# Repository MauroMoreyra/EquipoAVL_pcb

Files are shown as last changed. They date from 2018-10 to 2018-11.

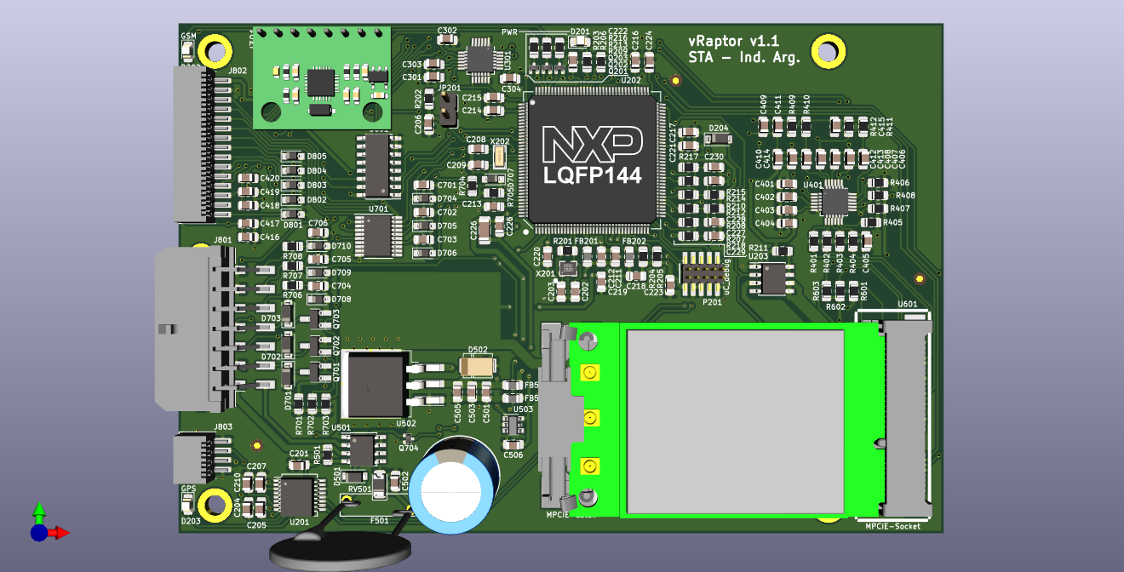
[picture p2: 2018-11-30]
TrackerAVL/images and 3d models/EquipoAVL_vRaptor_v1.1.png

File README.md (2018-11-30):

# EquipoAVL_pcb - vRaptor

## Guía rápida para manejo de versiones

- Habilitar modulo GitFlow en GitKraken.
- Creación de nueva versión: estando posicionado en rama "develop" o "master", GitFlow > Start Release > Nombre "vX.X" (número de versión).
- Finalización de nueva versión: GitFlow > Finish release, tildando "Delete branch". De esta forma se vuelcan a las ramas "develop" y "master" los cambios de la versión del release. A su vez se genera un TAG con el nombre del release "vX.X", que quedará de referencia histórica para futura consulta.

## Mejoras pendientes (previa validación)

- PCB 4 capas.
- Componentes en ambas caras.
- Revisar tamaño huellas, encapsulados.
- Modificar huellas para que posean el área que las delimita, así se valida el ERC en forma integral (con todos los checks activados).
- Ver otros errores del ERC integral.
- Verificar diseño 1.1 y corregir errores en caso de que existan.
- Verificar margenes tolerados por fabricantes, con el fin de achicar tamaños pistas y separación entre las mismas.
- Agregar información a componentes (desde esquemático).
- Poner conector DB15 en PCB, para utilizar así un cable VGA-DB15 directamente hacia la consola. Revisar tema gabinete.
- Capacitor C504 modificar para que sea de menor tamaño, reducir capacidad? low profile? investigar. Es muy alto (25mm).
- Revisar margenes laterales por tema gabinete - guia para su inserción. Revisar componentes situados muy sobre los bordes.
- Footprints IPC compatible: Revisar normativa IPC 7351 referente a los footprints recomendados de los componentes, ya que no es aconsejable utilizar los footprints recomendados por los fabricantes de las partes (se puede observar que para un mismo encapsulado, distintos fabricantes recomiendan footprints distintos, aunque varíen muy levemente). Revisar generador de footprints que sigue normativa IPC: https://www.pcblibraries.com/ a través del Library Expert.
- Footprints IPC compatible: Revisar densidad de componentes. Esto define el keepout del footprint, o sea, la distancia minima de separación con otro componente. Se recomienda usar una densidad "Normal" según el Library Expert.
- Revisar Bottom Paste de componentes de potencia (ej: LD1085), ya que IPC recomienda una "huella" de pasta de estaño con características especiales (tipo grilla, vías o microvías de disipación en cierta ubicación, etc.).

## Historial de versiones

**Versión 1.1**
- [Referencias de diseño](https://github.com/MauroMoreyra/EquipoAVL_pcb/blob/release/vRaptor-v1.1/Referencias%20de%20dise%C3%B1o%20v1.1.md).
- Se corrige el acceso de las pistas a los pads de los componentes, ahora lo hacen a 90° (no en diagonal). También, en caso de que a un pad entre y salga una pista, ahora ambas lo hacen con el mismo grosor (regla de diseño: ancho pista menor ancho pad, ya que facilita así el soldado de los componentes al no haber tanta transferencia térmica sobre las pistas).
- Se redimensiona el ancho de pistas, muchas se angostaron.
- Se modifican huellas de componentes QFN (```MPU-6050``` y ```NAU8814```), ahora tienen pads más largos (1.5mm) para facilitar el soldado manual (ese es el ancho de la    superficie del pad que la punta del soldador debe hacer contacto -punta ```900m-t-2c``` preferentemente).
- Se agrega tira de pines sobre conexiones de ```MPU-6050``` para tener como alternativa la posiblidad de colocar placa arduino de ese componente (inserción más fácil).

**Versión 1.0**
- Primera versión, entregable de materia Diseño de PCB.

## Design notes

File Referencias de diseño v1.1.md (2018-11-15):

## Referencias de diseño

- Mayer (Tecnología 8 mils)
- Pistas: 1.5; 1; 0.75; 0.5; 0.25; 0.20 [mm]
- Vías: 0.8 - Agujero: 0.4 [mm]
- Márgen: 0.25 mm
- Pista más delgada: 0.2 mm
- Dist. a borde: 0.3 mm

## STACK-UP

- FR4 1.6 mm Dual layer
- Componentes en capa superior
- Máscara anti-soldante: Azul
- Sin requerimientos especiales
- Terminación: HASL c/Pb
- Espesor de Cu: 1oz

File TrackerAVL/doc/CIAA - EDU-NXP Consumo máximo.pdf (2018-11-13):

Hola Juan,

Ya tengo armado el cálculo de potencia o de consumo para la EDU-CIAA.

Lo puntos más importantes serian:

- Según la hoja de datos del LPC4337 potencia máxima de disipación de del micro que es de 1,5W, lo que da una corriente máxima de 450mA.
- Como dato extra esta tiene un calculo de consumo del micor con un while(1) y sin periféricos habilitados:

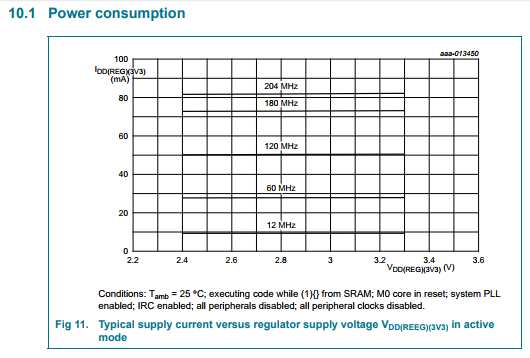
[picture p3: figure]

- A todo esto hay que sumarle el consumo del chip FTDI2232 que es de 30mA.

Así que estiramos alrededor de 500mA de consumo.

Otro dato extra: hay un link (seguramente lo conoces), que está bastante piola para sacar el ancho de la pista en forma sencilla:

hp://circuitcalculator.com/wordpress/2006/01/31/pcb-trace-width-calculator/

Por ultimo en el impreso de la EDU-CIAA la pista es de 30mils (aprox 1,5A), mas que suficiente para la aplicación.

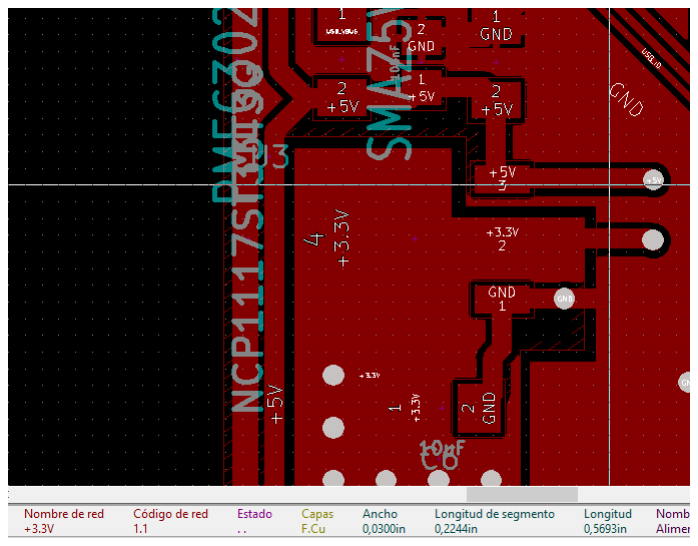
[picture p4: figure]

Avisame en que otra cosa te puedo ayudar,

Saludos,

Jorge.

### Re: Miercoles 30 de 19 a 22 en CADIEEL

1 de 1 | 13/09/2017 04:49 p.m.

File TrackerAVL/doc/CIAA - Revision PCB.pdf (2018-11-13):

# Revisión de PCB

Autor | Koenig Mauro
Versión | 0.1
Ultima revisión | 30-04-2014

Revisión PCB de la CIAA | Emtech S.A.

Página 2 de 8

### Contenido

Revisión de esquemático de la CIAA | Emtech S.A.

Página 3 de 8

### Revisiones

Fecha | Versión | Modificaciones
Febrero 3, 2014 0.1 | | Versión original

Página 4 de 8

## Introducción

El siguiente documento detallan comentarios sobre el diseño PCB de la CIAA-NXP y las tareas realizadas sobre el mismo.

Página 5 de 8

## Revisión

Lista de modificaciones a realizar al diseño: _Agregar los holes de 4mm OK
_Agregar 2 pines +24VDC a P12 OK
_Cambio de Part Number de TH9 a MF-MSMF110. OK _Cambiar ubicación de leds dentro de ventana. OK _Alineación de MOSFET. OK
_Cambiar C16 a EMVA350ARA471MKE0S OK
_Cambiar P8 a CONN HDR 1.27MM SMD AU 10POS
(http://www.digikey.com/product-detail/es/M50-3600542/952-1389-ND/2264370) OK _Agregar fiduciales OK
_Rehacer conectores USB, colocar MICRO USB.OK
_Cambiar el DB9 por PN:K22X-E9P-NJ, http://www.mouser.com/ds/2/222/K22X-220929.pdf OK _BT1, hay que intercambiar pin 2 con 3 OK
_Ver PAD GND de U1. OK

SEGUNDA REVISIÓN:

1. ¿Es posible aumentar el tamaño de los pads de T1...T12 (NSI45020)? Esto es para mejorar su disipación térmica, porque estamos un poco jugados en este sentido. Aunque sea dibujarles un rectángulo de cobre encima a cada pad, o directamente agrandar un poco los pads en la librería, creo que así es más rápido. Insisto en que necesitamos sí o sí mejorar la disipación térmica de estos reguladores.
OK se pasaron de 0.007 x 0.0035 a 0.009 x 0.005
2. ¿Se pueden agregar dos agujeros más de 4mm como los de las esquinas, pero para sujetar las expansiones que se conecten al PCB de la CIAA? Vemos que hay lugar abajo a la izquierda (a la derecha de los conectores USB) y abajo a la derecha (a la izquierda del conector DB9).
Agregados dos agujeros de 4 mm y uno de 2.5mm entre los conectores de expansión.
3. ¿Se puede girar un poco más el conector BT1 en sentido de las agujas del reloj? Creemos que al colocar la batería, ésta podría tocar contra el primer pin de la bornera J19.
Se giró 10º más, creo que si lo giramos más, puede tocar la chapa del soporte en el pin de J19

### 4. _Micro USB: Según esto, el borde del PCB debe estar a 1.45mm del

centro de los pads, y en el PCB de la CIAA yo medí 2.3mm. Corregido.

### 5. _Disipación térmica de los NSI45020 (T1...T12). Tendríamos que tratar

al menos de acercarnos a los 100mm^2 de área por pad, es decir cada pad debería ser de 1cm x 1cm. Sé que esto es casi imposible, pero si al menos dibujas un polígono de 10mm x 10mm asociado a la net de

Página 6 de 8

cada pad, que el KiCad lo rellene como pueda sin tocar otros nets, así nos acercamos lo más que podamos a ese área. ¿Me explico? Tenemos que tratar de sumar superficie de cobre de la forma que podamos.
Con respecto a T1 a T8 va mi consulta: En serie con estos diodos esta lo siguiente:
Diodo LL4148 200mA
Led LED ALG 0603 SMD de 72mW
Diodo de PS2801 70mW
y una R0603 100ohms 100mW que limita la corriente de entrada.

En verdad creen que hace falta modificar los pads? Perdón si estoy omitiendo alguna función más de estos reguladores, mi consulta surge porque la zona donde están ubicados realmente está muy poblada y los cambios van a ser notables si se necesitan estos PADs grandes. Rta:
Las cuentas de disipación están basadas en unos cálculos simples: Si el rango de tensión va de 5V a 24 (o 30V) de entrada, y queremos que por el foto diodo siempre circulen en el orden de los 10mA alguien tiene que hacer de elemento variable...eso lo hace la fuente de corriente NSI. El costo para tener este rango amplio es que no está calculado para una tensión de entrada fija, y con una R en serie lo solucionamos. Si así lo hiciéramos igual la R debería disipar... Ahora, en el peor caso tenemos 30V de entrada, quitando la caída en el 4148, el LED, etc. quedarán unos 25V regulados a 10mA de entrada => 250mW para disipar en el NSI. Con 100mm^2 en 1Oz. de cobre tiene una Rtja de 600°C/W (datasheet) da 150 grados de sobre elevación...si esto lo duplicamos por ponerlo esa superficie en cada pad la cosa baja a la mitad, 75 grados.
Una alternativa rápida que se me ocurre sería poner el NSI conectado a la Net "COM", cambiando el orden de los componentes en serie. En este caso dado que "COM" está ruteado en la capa del plano de tierra, se podría hacer allí el plano común a todos los NSI relativamente fácil, y colocando varias vías térmicas en el cátodo de cada NSI logramos buena conductividad...

MEJORADO

6. Todas las trazas a borneras en general deben ser de 20mils (Relays, MOSFET, +24), en líneas generales desde J10 a J15 todas las salidas digitales
AGREGADO

### 7. Anchos de traza hacia las borneras, como dice Juan, deberían ser de 0.5 o 0.75mm como mínimo. Por ejemplo la N-00000437, que saca

24V a través del polyswitch de 1A. Habría que chequear todas las pistas que llegan a los bornes.
AGREGADO

### 8. Los transceivers RS485 compatibles con Profibus que encontramos

son todos de 5V. Después de conversarlo con Juan, para simplificarte (al menos un poco) el trabajo, pensamos que es mejor no poner el

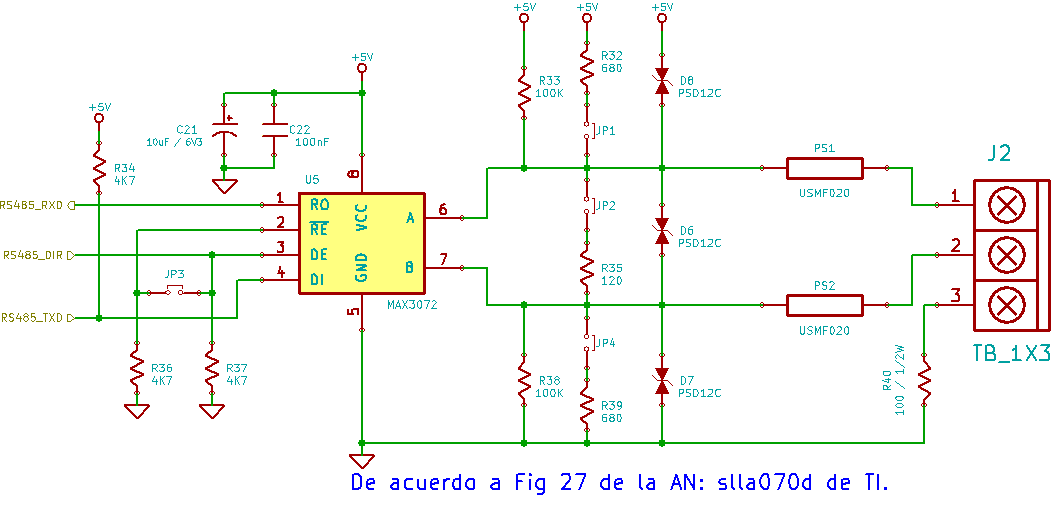
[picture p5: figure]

Página 7 de 8

puente soldable y cambiar todo el circuito RS485 a 5V. Te pego acá una imagen de cómo quedaría el esquemático (básicamente cambié los puntos +3.3V a +5V). Juan me avisó que los resistores del bus también cambian, pero eso no afecta el ruteo, así que por ahora dejamos esos valores.

CAMBIADO

### 9. Orden de los LEDs IN: 0 1 2 3 4 5 7 6 y LEDs DOUT: 5 4 7 6. Aunque

está perfecta la aclaración en el silkscreen, yo trataría de ordenar los LEDs para que queden en orden.
CORREGIDO

### 10. Los cuatro agujeros están "casi bien", pero creo que se puede mejorar

un poco su ubicación. O sea, la distancia entre H3 y H2 creo que es alrededor de un 1 mm mayor a lo que debería ser, y la distancia entre H3 y H1 es alrededor de 2 mm mayor a la que debería ser. CORREGIDO
11. Además se aprecia que queda algo de espacio para agrandar el PCB, que creo que como máximo podría andar en alrededor de 138 x 86 mm.

### 12. En el esquemático del proyecto que envió Mauro, la numeración de los

pines del relé no es la misma que en el esquemático.
VERIFICADO

### 13. Tema la Pila CR2032, la verdad que no me convence mucho la

ubicación, van un par de sugerencias:
a) Cambiar de CR2032 a CR2016, va link a hojas de datos para que vean la diferencia de formato y las especificaciones. http://data.energizer.com/PDFs/cr2032.pdfhttp://data.energizer.com/PDFs/cr2016.pdf
b) Cambiar la ubicación, ponerla debajo de los USB, es decir diagonalmente opuesta, y usar porta batería SMD. Estuve viendo y no parece muy difícil, pero Mauro nos lo puede decir mejor.

### 14. Me parece que todas las tiras de pines están muy juntas, que se va

complicar al momento de armado, P12, P15 Y P9, y además P14 contra los relés.
REVISADO, SIN MODIFICACION

### 15. Planos de masa, GND y GNDA están unidos tan solo en un punto en

Inner1_cu, cerca del micro. Yo suelo tomar como referencia la nota de

Página 8 de 8

aplicación adjunta, que en el caso nuestro sugiere la conexión en más de un punto.
16. Cambiar en esquemático pin out de Q2, Q4, Q8 y Q2, cambiar a G=1, D=2 y S=3. Unir con una traza de 20mils el pad TAB y pin 2. CORREGIDO

### 17. Cambiar el footprint de C1 C5 C18 C31 C34 C60 C68 C78 C21 C28 a

CAP TANT 10UF 6.3V 10% 1206 PN:T491A106K006AT7280 CORREGIDO

### 18. Cambio de C67 a 0603

CORREGIDO

### 19. Cambiar encapsulado de FTDI U17 a paso .5mm

CORREGIDO
20. Modificar vias a 25mils de diámetro y un hole de 10 mils. MODIFICADO.

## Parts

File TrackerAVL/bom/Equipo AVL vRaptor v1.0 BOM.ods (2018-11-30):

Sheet: BOM
Componente | Fabricante | Cant. | Referencia | Descripción | Código Digi-Key | Link | Comentario
ACELERÓMETROS
MPU-6050 (IC) | TDK InvenSense | 1 |  | IMU ACCEL/GYRO 3-AXIS I2C 24QFN | 1428-1007-1-ND | https://www.digikey.com/product-detail/en/tdk-invensense/MPU-6050/1428-1007-1-ND/4038010 | -
MPU-9150 (IC) | TDK InvenSense | 1 |  | IMU ACCEL/GYRO/MAG I2C 24LGA | 1428-1009-1-ND | https://www.digikey.com/product-detail/en/tdk-invensense/MPU-9150/1428-1009-1-ND/4038014 | -
MPU-9250 (IC) | TDK InvenSense | 1 |  | IMU ACCEL/GYRO/MAG I2C/SPI 24QFN | 1428-1019-1-ND | https://www.digikey.com/product-detail/en/tdk-invensense/MPU-9250/1428-1019-1-ND/4626450 | -
MÓDULO GSM/GPS
UC20-G Mini PCIe | Quectel | 1 |  | UMTS/HSPA+/GNSS Module | N/A
Conector mini PCIe PCB Hembra | Molex | 1 | PN 0679100002 | CONN PCI EXP MINI FEMALE 52POS | WM3470CT-ND | https://www.digikey.com/product-detail/en/molex-llc/0679100002/WM3470CT-ND/2405686 | -
IBUTTON
iButton DS1990A-F5+ | Maxim Integrated | 1 |  | IBUTTON SERIAL NUMBER F5 | DS1990A-F5+-ND | https://www.digikey.com/product-detail/es/maxim-integrated/DS1990A-F5/DS1990A-F5-ND/1769200 | -
Lector iButton DS9092T# | Maxim Integrated | 1 |  | IBTN PROBE W/TACTILE FEEDBACK | DS9092T#-ND | https://www.digikey.com/product-detail/es/maxim-integrated/DS9092T/DS9092T-ND/1768860 | -
Soporte iButton DS9093A+-ND | Maxim Integrated | 1 |  | IBUTTON KEY RING MOUNT BLACK | DS9093A+-ND | https://www.digikey.com/product-detail/es/maxim-integrated/DS9093A/DS9093A-ND/1769386 | -
Rf433 transceiver C1101
CONECTORES EQUIPO AVL
Connector Molex Micro-Fit 3.0 14 pos PCB Header | Molex | 1 | 430451406 | MICROFIT 3.0 RA SMT/CLIP DR TIN | WM10725TR-ND | https://www.digikey.com/product-detail/es/molex-llc/0430451406/WM10725TR-ND/3310229 | IO (10); POWER (4) | https://www.molex.com/molex/products/datasheet.jsp?part=active/0430451406_PCB_HEADERS.xml
Connector Molex Micro-Fit 3.0 14 pos Crimp Housing | Molex | 1 | 430251400 | CONN RECEPT 14POS 3MM DUAL ROW | WM2489-ND | https://www.digikey.com/product-detail/es/molex-llc/0430251400/WM2489-ND/531405 | IO (10); POWER (4) | https://www.molex.com/molex/products/datasheet.jsp?part=active/0430251400_CRIMP_HOUSINGS.xml
Micro-Fit 3.0 Crimp Terminal 20-24 AWG | Molex | 14 | 43030-0001 | CONN TERM FEMALE 20-24AWG TIN | WM1837CT-ND | https://www.digikey.com/product-detail/es/molex-llc/43030-0001/WM1837CT-ND/467810 | IO (10); POWER (4) | https://www.molex.com/molex/products/datasheet.jsp?part=active/0430300001_CRIMP_TERMINALS.xml
Connector Molex Pico-SPOX 4 pos PCB Header | Molex | 1 | 874380443 | CONN HEADER 4POS 1.5MM R/A SMD | WM7648TR-ND | https://www.digikey.com/product-detail/es/molex-llc/0874380443/WM7648TR-ND/699148 | PROG, SERIAL (4) | https://www.molex.com/molex/products/datasheet.jsp?part=active/0874380443_PCB_HEADERS.xml
Connector Molex Pico-SPOX 4 pos Crimp Housing | Molex | 1 | 874390400 | CONN HOUSING 4POS 1.5MM W/RAMP | WM2088-ND | https://www.digikey.com/products/es?keywords=87439-0400 | PROG, SERIAL (4) | https://www.molex.com/molex/products/datasheet.jsp?part=active/0874390400_CRIMP_HOUSINGS.xml
Pico-SPOX Crimp Terminal 24-26 AWG | Molex | 4 | 874210000 | CONN TERM FEMALE 24-30AWG TIN | WM9234TR-ND | https://www.digikey.com/product-detail/es/molex-llc/0874210000/WM9234TR-ND/2037270 | PROG, SERIAL (4) | https://www.molex.com/molex/products/datasheet.jsp?part=active/0874210000_CRIMP_TERMINALS.xml
Connector Molex Pico-SPOX 15 pos PCB Header | Molex | 1 | 87438-1543 | CONN HEADER 15POS 1.5MM R/A SMD | WM7659TR-ND | https://www.digikey.com/products/es?keywords=87438-1543 | INTERFAZ USR (15) | https://www.molex.com/molex/products/datasheet.jsp?part=active/0874381543_PCB_HEADERS.xml
Connector Molex Pico-SPOX 15 pos Crimp Housing | Molex | 1 | 87439-1500 | CONN HOUSING 15POS 1.5MM W/RAMP | WM2099-ND | https://www.digikey.com/product-detail/es/molex-connector-corporation/87439-1500/WM2099-ND/561778 | INTERFAZ USR (15) | https://www.molex.com/molex/products/datasheet.jsp?part=active/0874391500_CRIMP_HOUSINGS.xml
Pico-SPOX Crimp Terminal 24-26 AWG | Molex | 15 | 874210000 | CONN TERM FEMALE 24-30AWG TIN | WM9234TR-ND | https://www.digikey.com/product-detail/es/molex-llc/0874210000/WM9234TR-ND/2037270 | INTERFAZ USR (15)
CONECTORES CONSOLA
Connector D-Sub 15 pos, 3 rows, male pins |  | 1 |  | CONN D-SUB HD PLUG 15POS STR | 609-4042-ND | https://www.digikey.com/product-detail/en/amphenol-fci/10090769-P154ALF/609-4042-ND/2350290 | -
Connector D-Sub 15 pos, 3 rows, female sockets, for PCB |  | 1 |  | CONN DSUB HD RCPT 15POS R/A SLDR | 609-2802-ND | https://www.digikey.com/product-detail/en/amphenol-fci/ICD15S13E6GV00LF/609-2802-ND/1090326 | -
Connector D-Sub 15 pos, 2 rows, male pins |  | 1 |  | CONN D-SUB PLUG 15P STR SLDR CUP | G17S1510110EU-ND | https://www.digikey.com/product-detail/en/amphenol-commercial-products/G17S1510110EU/G17S1510110EU-ND/1242623 | -
Connector D-Sub 15 pos, 2 rows, female sockets, for PCB |  | 1 |  | CONN D-SUB RCPT 15POS R/A SOLDER | 609-1498-ND | https://www.digikey.com/product-detail/en/amphenol-fci/D15S33E4GV00LF/609-1498-ND/1001812 | -
Considerar usar un cable tipo VGA (ya hecho), y en el extremo opuesto “cortarlo” y colocar conector a equipo AVL. Consultar a OJOS del CIELO por largo estimado de cable. Revisar si en CHINA ya lo pueden enviar armado
AUDIO
Parlante
Micrófono
VARIOS
CI Optoacoplador para señales / cables hacia interfaz conductor |  | 1
En PCB Ojos del Cielo UNEX
FSA2567 |  |  |  | DUAL SIM SWITCH
AT45DB041D-SU | Adesto Technologies |  |  | Memoria flash tipo NOR |  | https://ar.mouser.com/ProductDetail/Adesto-Technologies/AT45DB041D-SU?qs=S%2FDyAMLKE9jN%2FzBcXSlSQg%3D%3D | -
CD4099 |  |  |  | 8-Bit Addressable Latch |  | http://www.sycelectronica.com.ar/semiconductores/CD4099.pdf | -
CD4512 |  |  |  | CMOS 8-Channel Data Selector |  | http://www.sycelectronica.com.ar/semiconductores/CD4512.pdf | -
MC908AP32 |  |  |  | uC
SN74LV4052A |  |  |  | Dual 4-Channel Analog Multiplexers and Demultiplexers

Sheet: Análisis_codec_audio_NAU8814
BOM NAU | https://www.digikey.com/products/es/capacitors/ceramic-capacitors/60?k=capacitor+4.7uF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 | - | Item | Cantidad
R1 | 1K2 |  | R = 1K2 | 2
R2 | 1K2 |  | C = 1uF | 4
C1 | 4.7uF | LOW ESR | C = 4.7uF | 6
C2 | 4.7uF | LOW ESR
C3 | 4.7uF | LOW ESR
C4 | 4.7uF | LOW ESR
C5 | 1uF | LOW ESR
C6 | 4.7uF | LOW ESR
C7 | 1uF | LOW ESR
C8 | 1uF | LOW ESR
C9 | 4.7uF | LOW ESR
C10 | 1uF | LOW ESR

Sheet: Análisis_conectores_de_borde
 |  | POSICIONES | DESCRIPCION | TIPO DE PROTECCIÓN
CONECTOR MOLEX MICRO-FIT 3.0 | 10 para IO An/Dig: | 10
Ver catalogo DIGIKEY: | > 1 dig. Para sensado de contacto (ignición) |  |  | Divisor resistivo + Zener |  | Verificar
https://www.digikey.com/products/es/connectors-interconnects/rectangular-connectors-headers-male-pins/314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 | > 6 entradas An y Dig
Catálogo WEB MOLEX | > 3 salidas Dig |  |  | Tipo Open collector? O Open Drain? |  | Verificar
https://www.molex.com/molex/products/listview.jsp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 | 4 para POWER | 4
https://www.molex.com/molex/product-search/products.action | > 1 VBAT
MOLEX Wire-to-Board Connectors | > 3 GND |  |  | PolyFuse
https://www.molex.com/molex/products/group?key=wire_to_board_connectors&channel=products | 4 para PROG / SERIAL | 4
MOLEX Micro Connector Products | > 2 GND
https://www.molex.com/molex/products/group?key=micro_connectors&channel=products | > TX |  |  | BUFFER | 1
 | > RX |  |  | BUFFER | 1
 | 15 para interfaz con conductor: | 15
 | > 4 teclado |  |  | BUFFER | 4
 | > 4 display |  |  | BUFFER | 4
 | > 2 spkr ±
 | > 2 mic ±
 | > 1 ibutton (opc.)
 | > 1 VCC |  |  | PolyFuse
 | > 1 GND
 | Posibles usos de IO An/Dig | 20 pos thru-hole > | https://www.digikey.com/product-detail/es/molex-llc/0430452000/WM4726-ND/531426
 | DEFINIR, para ver de qué cantidad es necesaria para reducir la cantidad | 24 pos thru-hole > | https://www.digikey.com/product-detail/es/molex-llc/0430452400/WM4728-ND/531428
 |  | 20 pos smd > | https://www.digikey.com/product-detail/es/molex-llc/0430452009/WM7075TR-ND/3044337
 | CONCLUSIONES:
 | > Usar conector thru-hole (para mayor resistencia al conexionado vs smd).
 | > Usar 3 conectores, divididos por funcionalidad: 1 para IO y POWER; 1 para PROG.; 1 para Interfaz conductor

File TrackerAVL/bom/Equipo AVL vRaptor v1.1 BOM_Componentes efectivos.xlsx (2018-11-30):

Id | Identificador | Empaquetado | Cantidad | Identificación | S/N | Cantidad real | Componentes Not Mounted | Comentario / Justificación
1 | J301 | PinHeader_1x08_P2.54mm_Vertical | 1 | Conn_01x08 | NO | 0
2 | H102,H101,H103,H104 | MountingHole_3.2mm_M3_Pad_Thin | 4 | MountingHole | NO | 0
3 | C401,C207,C201,C204,C205,C206,C210,C211,C212,C213,C214,C215,C216,C217,C218,C219,C220,C221,C222,C223,C224,C225,C227,C228,C229,C230,C301,C302,C303,C403,C406,C409,C410,C501,C502,C701,C702,C703,C704,C705,C706 | C_0805_2012Metric_Pad1.15x1.40mm_HandSolder | 41 | 100nF | SI | 38 | C206, C211, C212
4 | C304 | C_0805_2012Metric_Pad1.15x1.40mm_HandSolder | 1 | 2.2nF | SI | 1
5 | U401 | NAU8814_QFN-24_4x4mm_Pitch0.5mm_EPAD_HandSoldering | 1 | NAU8814 | SI | 1
6 | U301 | InvenSense_QFN-24_4x4mm_P0.5mm_HandSoldering | 1 | MPU-6050 | SI | 1
7 | U601 | mpcie-socket-latch | 1 | MPCIE-Socket | SI | 1
8 | U202 | LQFP144-M05 | 1 | LPC4337JBD144 | SI | 1
9 | U801 | SOIC-16_3.9x9.9mm_P1.27mm | 1 | 74HC4053 | SI | 1
10 | X201 | FA238V-XTAL | 1 | 12MHz | SI | 1
11 | U501,U203 | SOIC-8_3.9x4.9mm_P1.27mm | 2 | STS8C5H30L | SI | 1 | U203
12 | R501,R204,R205,R207,R210,R211,R214,R217,R405,R406,R407,R408,R601,R602,R603,R701,R702,R703 | R_0805_2012Metric_Pad1.15x1.40mm_HandSolder | 18 | 10K | SI | 17 | R211 | R211: por optarse secuencia de reset mediante #PERST
13 | FB502,FB501 | L_0805_2012Metric_Pad1.15x1.40mm_HandSolder | 2 | HZ0805E601R-10 | SI | 2
14 | C202,C203,C208,C209,C405 | C_0805_2012Metric_Pad1.15x1.40mm_HandSolder | 5 | 20pF | SI | 5
15 | C226 | C_1206_3216Metric_Pad1.42x1.75mm_HandSolder | 1 | 10uF 10V | SI | 1
16 | C402,C404,C407,C408,C411,C414,C420 | C_0805_2012Metric_Pad1.15x1.40mm_HandSolder | 7 | 4.7uF | SI | 7
17 | C412,C413 | C_0805_2012Metric_Pad1.15x1.40mm_HandSolder | 2 | 1uF | SI | 2
18 | C415 | C_0805_2012Metric_Pad1.15x1.40mm_HandSolder | 1 | 10nF | SI | 1
19 | C416,C418 | C_0805_2012Metric_Pad1.15x1.40mm_HandSolder | 2 | 10pF | SI | 2
20 | C417,C419 | C_0805_2012Metric_Pad1.15x1.40mm_HandSolder | 2 | 33pF | SI | 2
21 | C503,C505,C506 | C_0805_2012Metric_Pad1.15x1.40mm_HandSolder | 3 | 4.7uF 6.3V | SI | 3
22 | C504 | CP_Radial_D12.5mm_P5.00mm | 1 | 1000uF 50V | SI | 1
23 | D201 | LED_0805_2012Metric_Pad1.15x1.40mm_HandSolder | 1 | LED ROJO | NO | 0
24 | D202 | LED_0805_2012Metric_Pad1.15x1.40mm_HandSolder | 1 | LED AZUL | SI | 1
25 | D203 | LED_0805_2012Metric_Pad1.15x1.40mm_HandSolder | 1 | LED VERDE | SI | 1
26 | D204 | D_SOD-123 | 1 | 1N4148 | SI | 1
27 | D501 | D_SOD-123F | 1 | PMEG3020EH | SI | 1
28 | D502 | DO-214AC (SMA) | 1 | SMAZ5V6 | SI | 1
29 | D701,D702,D703 | D_SOD-123 | 3 | BZT52C36 | SI | 3
30 | D704,D705,D706,D707,D708,D709,D710,D801,D802,D803,D804,D805 | D_SOD-323_HandSoldering | 12 | PESD5V0L1UA | SI | 9 | D704, D705, D706 | D704, D705, D706: por existir protección mediante buffer
31 | F101,F102,F103,F104,F105,F106 | Fiducial_1mm_Dia_2mm_Outer | 6 | Fiducial | NO | 0
32 | F501 | 60R300XF | 1 | 60R300XF | SI | 1
33 | FB201,FB202 | L_0805_2012Metric_Pad1.15x1.40mm_HandSolder | 2 | MI0805M221R-10 | NO | 0 | FB201, FB202 | FB201, FB202: por no utilizarse funcionalidad USB
34 | J801 | Molex_Micro-Fit_3.0_43045-1406_2x07-1MP_P3.00mm_Horizontal | 1 | Conn_02x07_Odd_Even | SI | 1
35 | J802 | Molex_Pico_SPOX_87438-0443_1x15 | 1 | Conn_01x15 | SI | 1
36 | J803 | Molex_Pico_SPOX_87438-0443_1x04 | 1 | Conn_01x04 | SI | 1
37 | JP201 | PinHeader_1x02_P2.54mm_Vertical | 1 | JP | NO | 0
38 | JP202,JP203 | SolderJumper-2_P1.3mm_Open_Pad1.0x1.5mm | 2 | SolderJumper_2_Open | NO | 0
39 | P201 | Pin_Array_5x2_1.27mm_SMD | 1 | uC_debug | SI | 1
40 | Q201,Q202,Q203,Q704 | SOT-523_(SOT-416) | 4 | DTC043ZEBTL | SI | 3 | Q201 | Q201: por no utilizarse Led Rojo
41 | Q701,Q702,Q703 | SOT-23_Handsoldering | 3 | 2N7002P | SI | 3
42 | R201 | R_0805_2012Metric_Pad1.15x1.40mm_HandSolder | 1 | 10M | SI | 1
43 | R202 | R_0805_2012Metric_Pad1.15x1.40mm_HandSolder | 1 | 100K | SI | 1
44 | R203,R206 | R_0805_2012Metric_Pad1.15x1.40mm_HandSolder | 2 | 2K2 | SI | 2
45 | R208,R212,R215,R218,R409,R412 | R_0805_2012Metric_Pad1.15x1.40mm_HandSolder | 6 | 1K | SI | 6
46 | R209,R213,R216 | R_0805_2012Metric_Pad1.15x1.40mm_HandSolder | 3 | 680 | SI | 2 | R209 | R209: por no utilizarse Led Rojo
47 | R401,R402,R403,R404 | R_0805_2012Metric_Pad1.15x1.40mm_HandSolder | 4 | 22R | SI | 4
48 | R410,R411,R706,R707,R708 | R_0805_2012Metric_Pad1.15x1.40mm_HandSolder | 5 | 1K2 | SI | 5
49 | R704 | R_0805_2012Metric_Pad1.15x1.40mm_HandSolder | 1 | 10K 1% | SI | 1
50 | R705 | R_0805_2012Metric_Pad1.15x1.40mm_HandSolder | 1 | 1210 1% | SI | 1
51 | RV501 | D_1206_3216Metric_Pad1.42x1.75mm_HandSolder | 1 | 30VDC | SI | 1
52 | U201 | SSOP-16_5.3x6.2mm_P0.65mm | 1 | MAX3221 | SI | 1
53 | U502 | TO-263-3_TabPin2 | 1 | LD1085D2T33R | SI | 1
54 | U503 | TSOP-5_NCP114 | 1 | NCP114ASN180T1G | SI | 1
55 | U701 | TSSOP-20_4.4x6.5mm_P0.65mm | 1 | 74LVC244APW | SI | 1
56 | X202 | 32.768-XTAL-SMD | 1 | 32.768K | SI | 1
57 | JP401 | NetTie-2_SMD_Pad0.5mm | 1 | Jumper | NO | 0

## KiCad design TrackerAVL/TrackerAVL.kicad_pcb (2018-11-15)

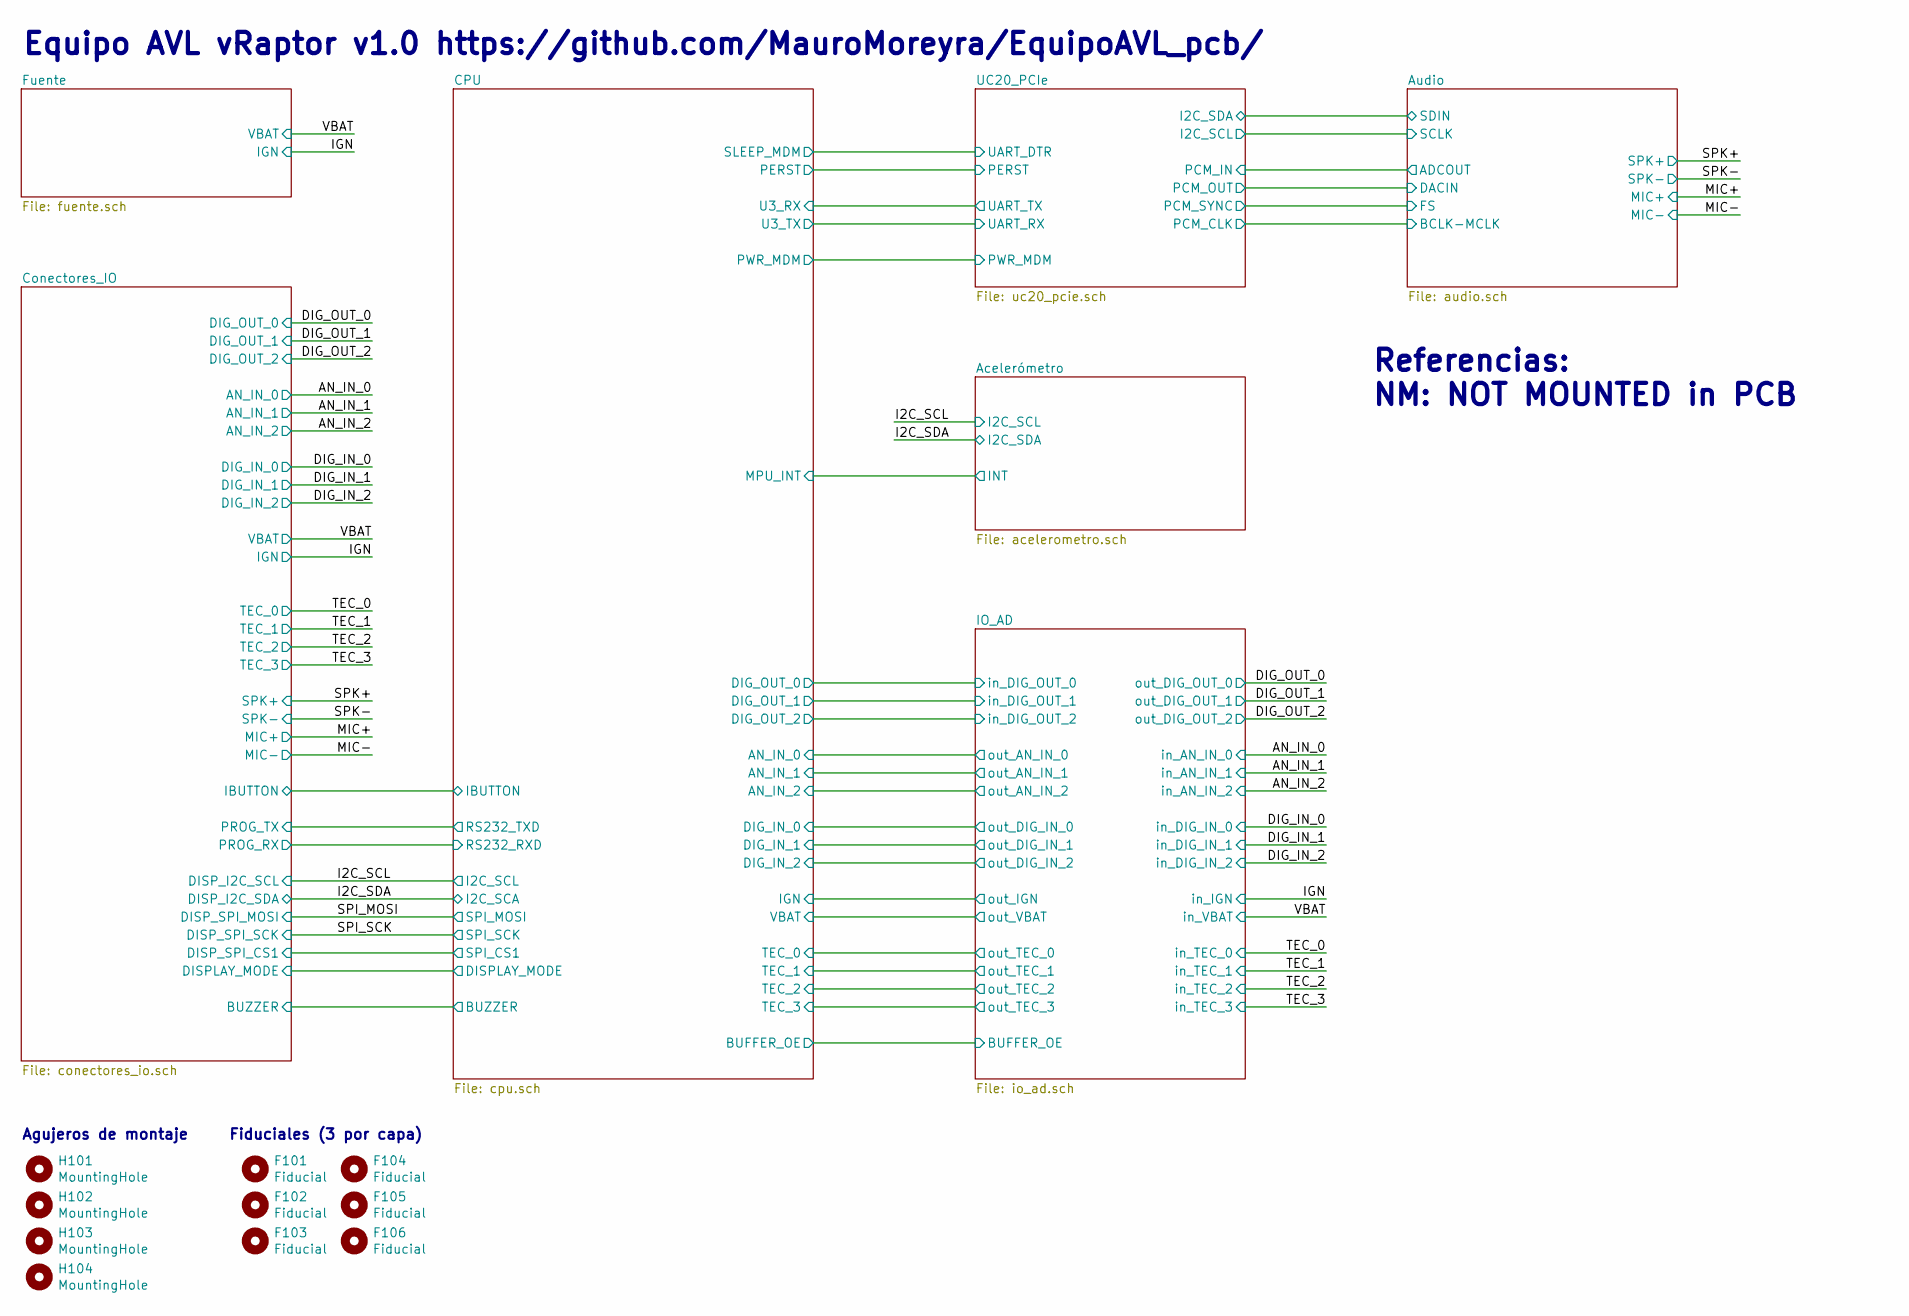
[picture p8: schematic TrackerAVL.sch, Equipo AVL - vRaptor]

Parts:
F101, F102, F103, F104, F105, F106: Fiducial; Fiducial_1mm_Dia_2mm_Outer
H101, H102, H103, H104: MountingHole; MountingHole_3.2mm_M3_Pad_Thin

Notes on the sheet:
Equipo AVL vRaptor v1.0 https://github.com/MauroMoreyra/EquipoAVL_pcb/
Referencias: NM: NOT MOUNTED in PCB
Agujeros de montaje
Fiduciales (3 por capa)

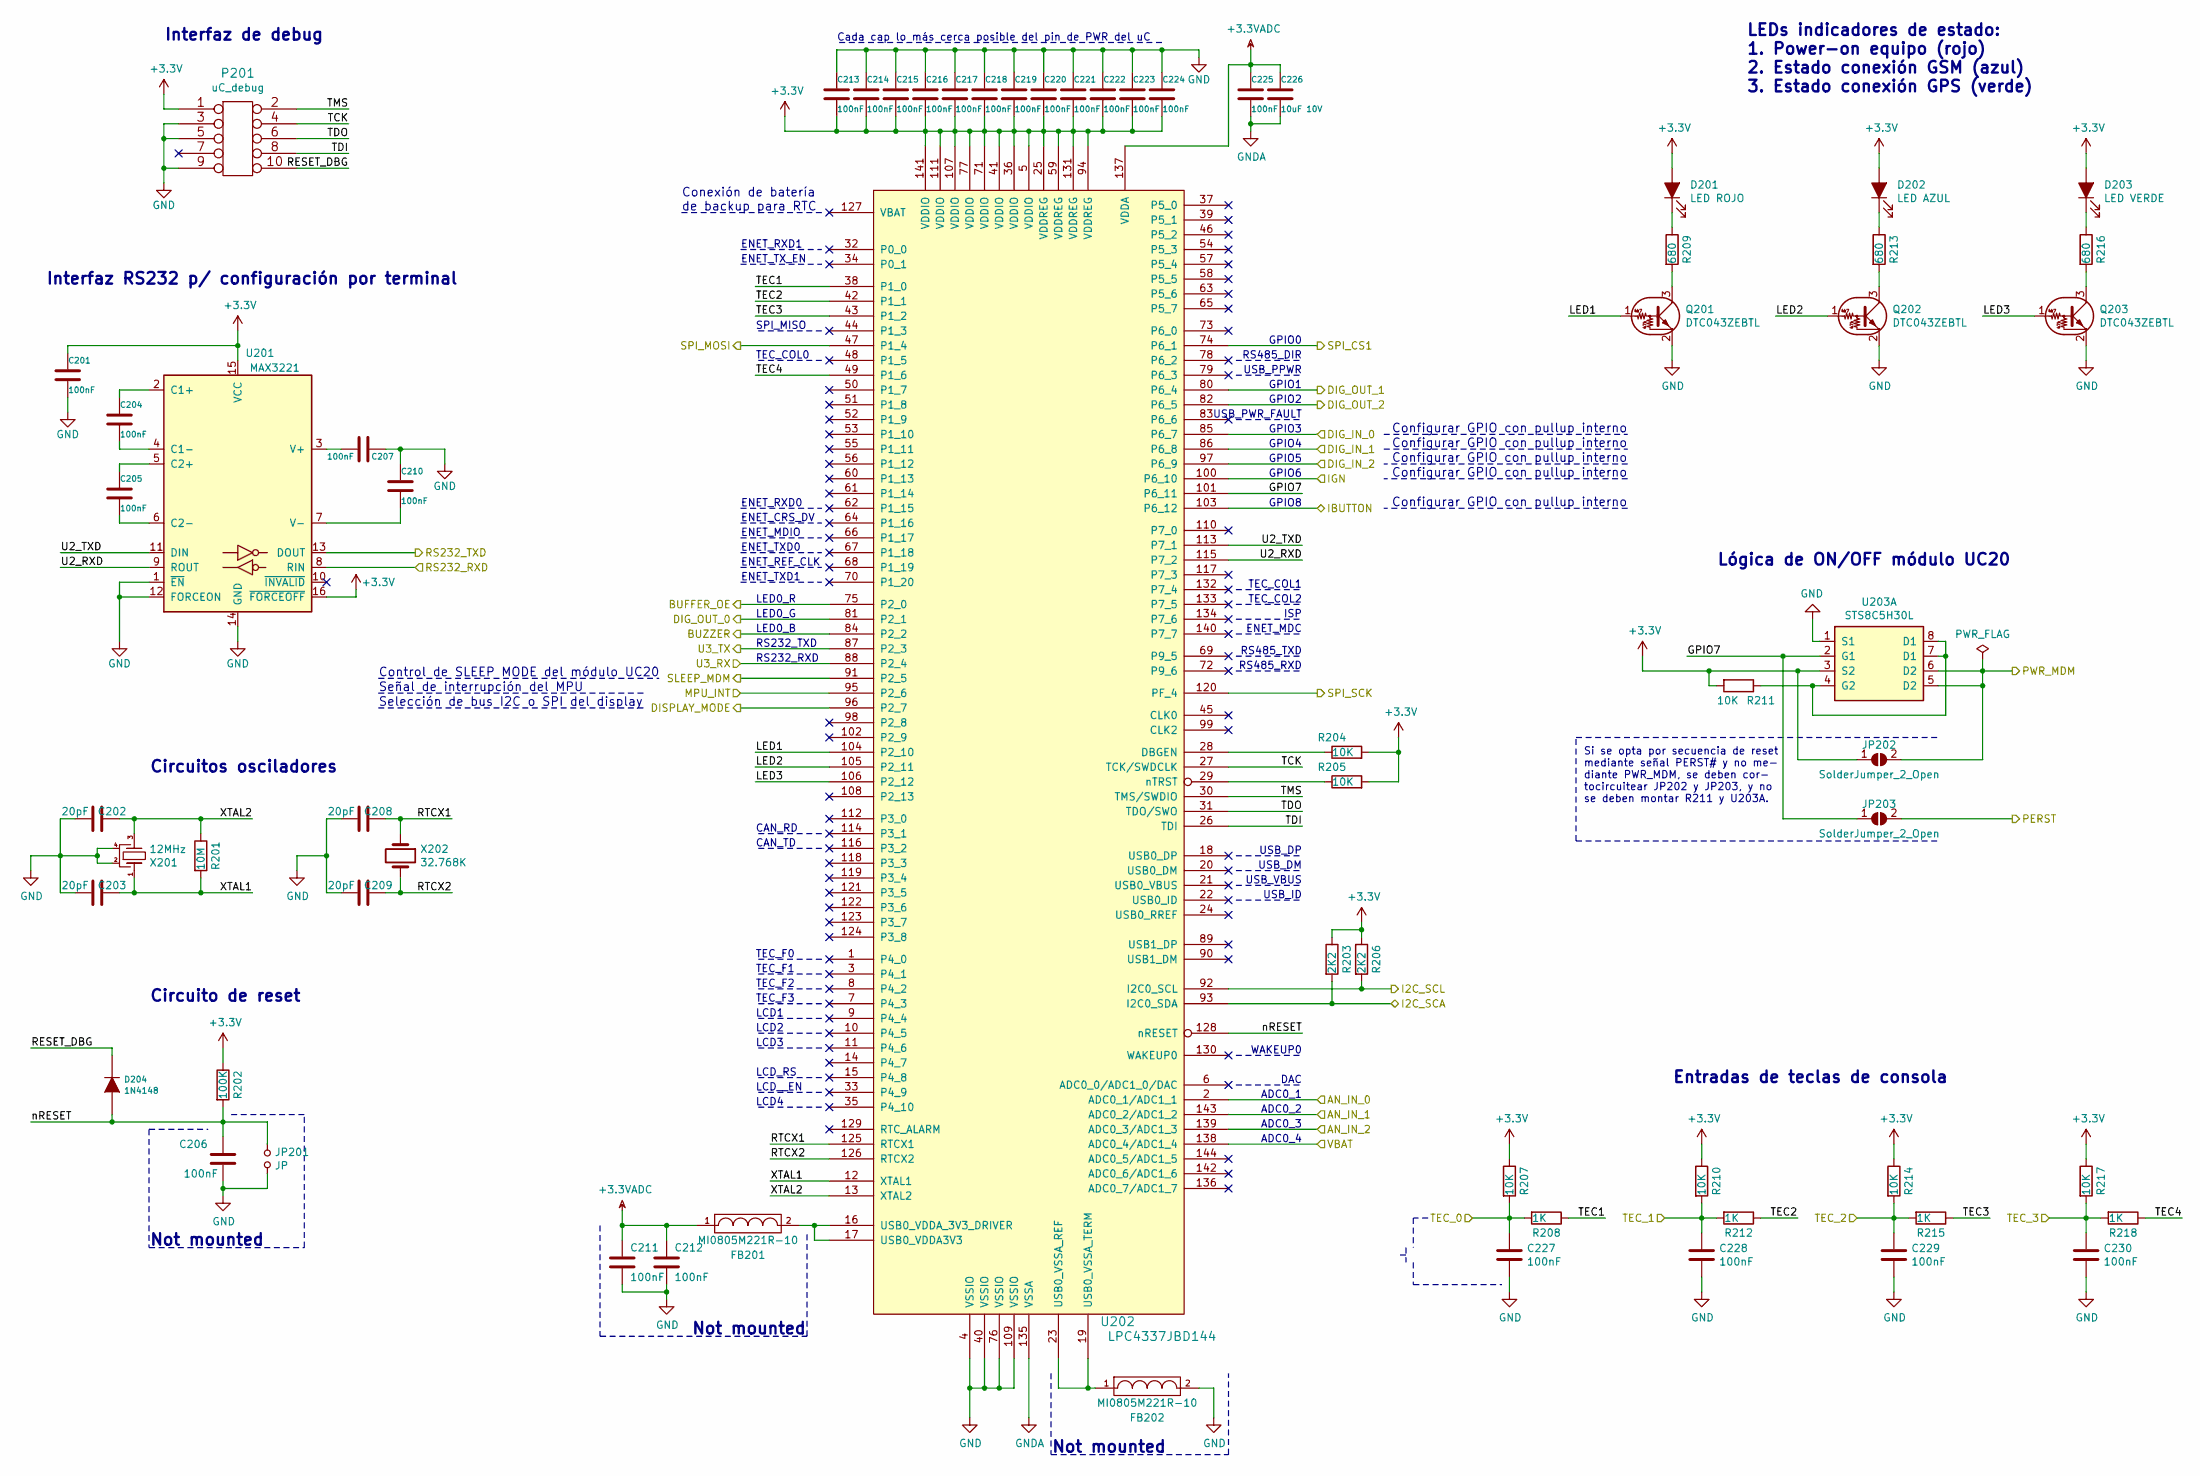
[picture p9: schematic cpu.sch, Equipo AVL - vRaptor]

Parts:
C201, C204, C205, C206, C207, C210, C211, C212, C213, C214, C215, C216, C217, C218, C219, C220, C221, C222, C223, C224, C225, C227, C228, C229, C230: 100nF; C_0805_2012Metric_Pad1.15x1.40mm_HandSolder
C202, C203, C208, C209: 20pF; C_0805_2012Metric_Pad1.15x1.40mm_HandSolder
C226: 10uF 10V; C_1206_3216Metric_Pad1.42x1.75mm_HandSolder
D201: LED ROJO; LED_0805_2012Metric_Pad1.15x1.40mm_HandSolder
D202: LED AZUL; LED_0805_2012Metric_Pad1.15x1.40mm_HandSolder
D203: LED VERDE; LED_0805_2012Metric_Pad1.15x1.40mm_HandSolder
D204: 1N4148; D_SOD-123
FB201, FB202: MI0805M221R-10; L_0805_2012Metric_Pad1.15x1.40mm_HandSolder
JP201: JP; PinHeader_1x02_P2.54mm_Vertical
JP202, JP203: SolderJumper_2_Open; SolderJumper-2_P1.3mm_Open_Pad1.0x1.5mm
P201: uC_debug; Pin_Array_5x2_1.27mm_SMD
Q201, Q202, Q203: DTC043ZEBTL; SOT-523_(SOT-416)
R201: 10M; R_0805_2012Metric_Pad1.15x1.40mm_HandSolder
R202: 100K; R_0805_2012Metric_Pad1.15x1.40mm_HandSolder
R203, R206: 2K2; R_0805_2012Metric_Pad1.15x1.40mm_HandSolder
R204, R205, R207, R210, R211, R214, R217: 10K; R_0805_2012Metric_Pad1.15x1.40mm_HandSolder
R208, R212, R215, R218: 1K; R_0805_2012Metric_Pad1.15x1.40mm_HandSolder
R209, R213, R216: 680; R_0805_2012Metric_Pad1.15x1.40mm_HandSolder
U201: MAX3221; SSOP-16_5.3x6.2mm_P0.65mm
U202: LPC4337JBD144; LQFP144-M05
U203: STS8C5H30L; SOIC-8_3.9x4.9mm_P1.27mm
X201: 12MHz; FA238V-XTAL; Digikey/Mouser 887-1831-1-ND
X202: 32.768K; 32.768-XTAL-SMD

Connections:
+3.3VADC: C211.1, C212.1, C225.1, C226.1, FB201.1, U202.137 (VDDA); also elsewhere on the board
+3V3: C201.1, C213.2, C214.2, C215.2, C216.2, C217.2, C218.2, C219.2, C220.2, C221.2, C222.2, C223.2, C224.2, D201.2 (A), D202.2 (A), D203.2 (A), JP202.1 (A), P201.1, R202.1, R203.1, R204.2, R205.2, R206.1, R207.1, R210.1, R211.2, R214.1, R217.1, U201.15 (VCC), U201.16 (~FORCEOFF), U202.5 (VDDIO), U202.25 (VDDREG), U202.36 (VDDIO), U202.41 (VDDIO), U202.59 (VDDREG), U202.71 (VDDIO), U202.77 (VDDIO), U202.94 (VDDREG), U202.107 (VDDIO), U202.111 (VDDIO), U202.131 (VDDREG), U202.141 (VDDIO), U203.3 (S2); also elsewhere on the board
/Acelerómetro/INT: U202.95 (P2_6); also elsewhere on the board
/CPU/AN_IN_0: U202.2 (ADC0_1/ADC1_1); also elsewhere on the board
/CPU/AN_IN_1: U202.143 (ADC0_2/ADC1_2); also elsewhere on the board
/CPU/AN_IN_2: U202.139 (ADC0_3/ADC1_3); also elsewhere on the board
/CPU/BUFFER_OE: U202.75 (P2_0); also elsewhere on the board
/CPU/BUZZER: U202.84 (P2_2); also elsewhere on the board
/CPU/DIG_IN_0: U202.85 (P6_7); also elsewhere on the board
/CPU/DIG_IN_1: U202.86 (P6_8); also elsewhere on the board
/CPU/DIG_IN_2: U202.97 (P6_9); also elsewhere on the board
/CPU/DIG_OUT_0: U202.81 (P2_1); also elsewhere on the board
/CPU/DIG_OUT_1: U202.80 (P6_4); also elsewhere on the board
/CPU/DIG_OUT_2: U202.82 (P6_5); also elsewhere on the board
/CPU/DISPLAY_MODE: U202.96 (P2_7); also elsewhere on the board
/CPU/GPIO7: JP203.1 (A), U202.101 (P6_11), U203.2 (G1)
/CPU/IBUTTON: U202.103 (P6_12); also elsewhere on the board
/CPU/IGN: U202.100 (P6_10); also elsewhere on the board
/CPU/LED1: Q201.1 (B), U202.104 (P2_10)
/CPU/LED2: Q202.1 (B), U202.105 (P2_11)
/CPU/LED3: Q203.1 (B), U202.106 (P2_12)
/CPU/PERST: JP203.2 (B); also elsewhere on the board
/CPU/PWR_MDM: JP202.2 (B), U203.5 (D2), U203.6 (D2); also elsewhere on the board
/CPU/RESET_DBG: D204.2 (K), P201.10
/CPU/RTCX1: C208.1, U202.125 (RTCX1), X202.1
/CPU/RTCX2: C209.1, U202.126 (RTCX2), X202.2
/CPU/SLEEP_MDM: U202.91 (P2_5); also elsewhere on the board
/CPU/TCK: P201.4, U202.27 (TCK/SWDCLK)
/CPU/TDI: P201.8, U202.26 (TDI)
/CPU/TDO: P201.6, U202.31 (TDO/SWO)
/CPU/TEC1: R208.1, U202.38 (P1_0)
/CPU/TEC2: R212.1, U202.42 (P1_1)
/CPU/TEC3: R215.1, U202.43 (P1_2)
/CPU/TEC4: R218.1, U202.49 (P1_6)
/CPU/TEC_0: C227.1, R207.2, R208.2; also elsewhere on the board
/CPU/TEC_1: C228.1, R210.2, R212.2; also elsewhere on the board
/CPU/TEC_2: C229.1, R214.2, R215.2; also elsewhere on the board
/CPU/TEC_3: C230.1, R217.2, R218.2; also elsewhere on the board
/CPU/TMS: P201.2, U202.30 (TMS/SWDIO)
/CPU/U2_RXD: U201.9 (ROUT), U202.115 (P7_2)
/CPU/U2_TXD: U201.11 (DIN), U202.113 (P7_1)
/CPU/U3_RX: U202.88 (P2_4); also elsewhere on the board
/CPU/U3_TX: U202.87 (P2_3); also elsewhere on the board
/CPU/VBAT: U202.138 (ADC0_4/ADC1_4); also elsewhere on the board
/CPU/XTAL1: C203.1, R201.2, U202.12 (XTAL1), X201.1 (A)
/CPU/XTAL2: C202.1, R201.1, U202.13 (XTAL2), X201.3 (B)
/CPU/nRESET: C206.1, D204.1 (A), JP201.1, R202.2, U202.128 (nRESET)
/Conectores_IO/DISP_SPI_CS1: U202.74 (P6_1); also elsewhere on the board
/Conectores_IO/PROG_RX: U201.8 (RIN); also elsewhere on the board
/Conectores_IO/PROG_TX: U201.13 (DOUT); also elsewhere on the board
/I2C_SCL: R206.2, U202.92 (I2C0_SCL); also elsewhere on the board
/I2C_SDA: R203.2, U202.93 (I2C0_SDA); also elsewhere on the board
/SPI_MOSI: U202.47 (P1_4); also elsewhere on the board
/SPI_SCK: U202.120 (PF_4); also elsewhere on the board
GND: C201.2, C202.2, C203.2, C206.2, C207.1, C208.2, C209.2, C210.1, C211.2, C212.2, C213.1, C214.1, C215.1, C216.1, C217.1, C218.1, C219.1, C220.1, C221.1, C222.1, C223.1, C224.1, C227.2, C228.2, C229.2, C230.2, FB202.2, JP201.2, P201.3, P201.5, P201.9, Q201.2 (E), Q202.2 (E), Q203.2 (E), U201.1 (~EN), U201.12 (FORCEON), U201.14 (GND), U202.4 (VSSIO), U202.40 (VSSIO), U202.76 (VSSIO), U202.109 (VSSIO), U203.1 (S1), X201.2 (GND), X201.4 (GND); also elsewhere on the board
GNDA: C225.2, C226.2, U202.135 (VSSA); also elsewhere on the board
unnamed: C204.1, U201.2 (C1+)
unnamed: C204.2, U201.4 (C1-)
unnamed: C205.1, U201.5 (C2+)
unnamed: C205.2, U201.6 (C2-)
unnamed: C207.2, U201.3 (V+)
unnamed: C210.2, U201.7 (V-)
unnamed: D201.1 (K), R209.1
unnamed: D202.1 (K), R213.1
unnamed: D203.1 (K), R216.1
unnamed: FB201.2, U202.16 (USB0_VDDA_3V3_DRIVER), U202.17 (USB0_VDDA3V3)
unnamed: FB202.1, U202.19 (USB0_VSSA_TERM), U202.23 (USB0_VSSA_REF)
unnamed: Q201.3 (C), R209.2
unnamed: Q202.3 (C), R213.2
unnamed: Q203.3 (C), R216.2
unnamed: R204.1, U202.28 (DBGEN)
unnamed: R205.1, U202.29 (nTRST)
unnamed: R211.1, U203.4 (G2), U203.7 (D1), U203.8 (VSS)

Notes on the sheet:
Configurar GPIO con pullup interno
LEDs indicadores de estado: 1. Power-on equipo (rojo) 2. Estado conexión GSM (azul) 3. Estado conexión GPS (verde)
Entradas de teclas de consola
WAKEUP0
USB_PWR_FAULT
USB_PPWR
RS485_DIR
TEC_COL2
TEC_COL1
CAN_RD
CAN_TD
TEC_F0
TEC_F1
TEC_F2
TEC_F3
LCD1
LCD2
LCD3
LCD_RS
LCD__EN
LCD4
Circuitos osciladores
Not mounted
ENET_TXD1
ENET_REF_CLK
ENET_TXD0
ENET_MDIO
ENET_CRS_DV
ENET_RXD0
TEC_COL0
ENET_TX_EN
ENET_RXD1
Conexión de batería de backup para RTC
ENET_MDC
ISP
RS485_TXD
RS485_RXD
Interfaz de debug
DAC
Circuito de reset

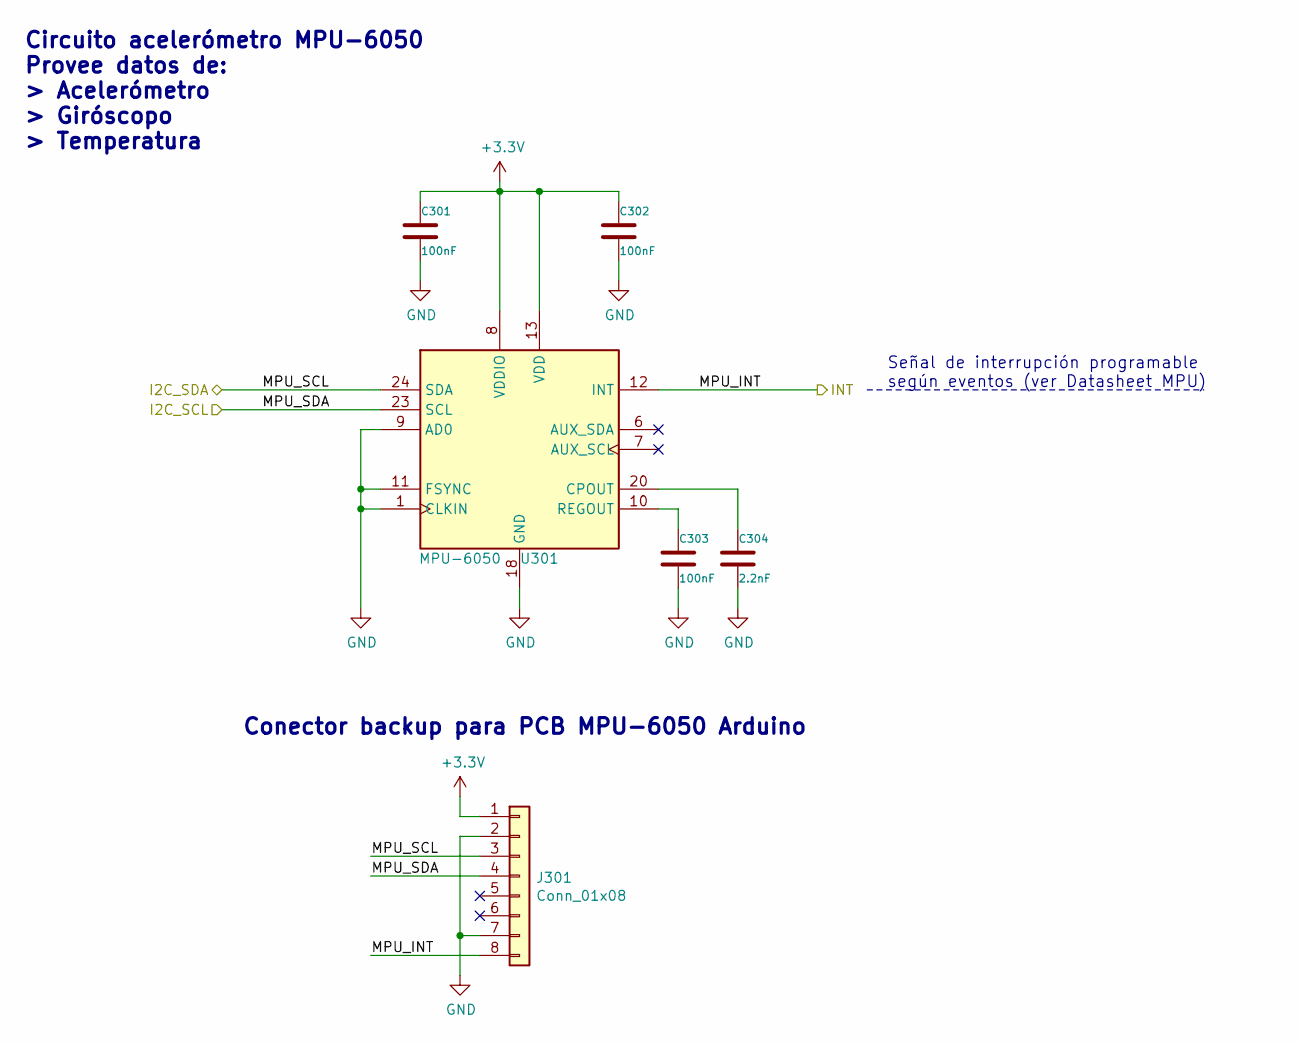
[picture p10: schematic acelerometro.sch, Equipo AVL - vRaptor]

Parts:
C301, C302, C303: 100nF; C_0805_2012Metric_Pad1.15x1.40mm_HandSolder
C304: 2.2nF; C_0805_2012Metric_Pad1.15x1.40mm_HandSolder
J301: Conn_01x08; PinHeader_1x08_P2.54mm_Vertical
U301: MPU-6050; InvenSense_QFN-24_4x4mm_P0.5mm_HandSoldering

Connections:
+3V3: C301.1, C302.1, J301.1, U301.8 (VDDIO), U301.13 (VDD); also elsewhere on the board
/Acelerómetro/INT: J301.8, U301.12 (INT); also elsewhere on the board
/I2C_SCL: J301.4, U301.23 (SCL); also elsewhere on the board
/I2C_SDA: J301.3, U301.24 (SDA); also elsewhere on the board
GND: C301.2, C302.2, C303.2, C304.2, J301.2, J301.7, U301.1 (CLKIN), U301.9 (AD0), U301.11 (FSYNC), U301.18 (GND); also elsewhere on the board
unnamed: C303.1, U301.10 (REGOUT)
unnamed: C304.1, U301.20 (CPOUT)

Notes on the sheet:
Circuito acelerómetro MPU-6050 Provee datos de: > Acelerómetro > Giróscopo > Temperatura
Señal de interrupción programable según eventos (ver Datasheet MPU)
Conector backup para PCB MPU-6050 Arduino

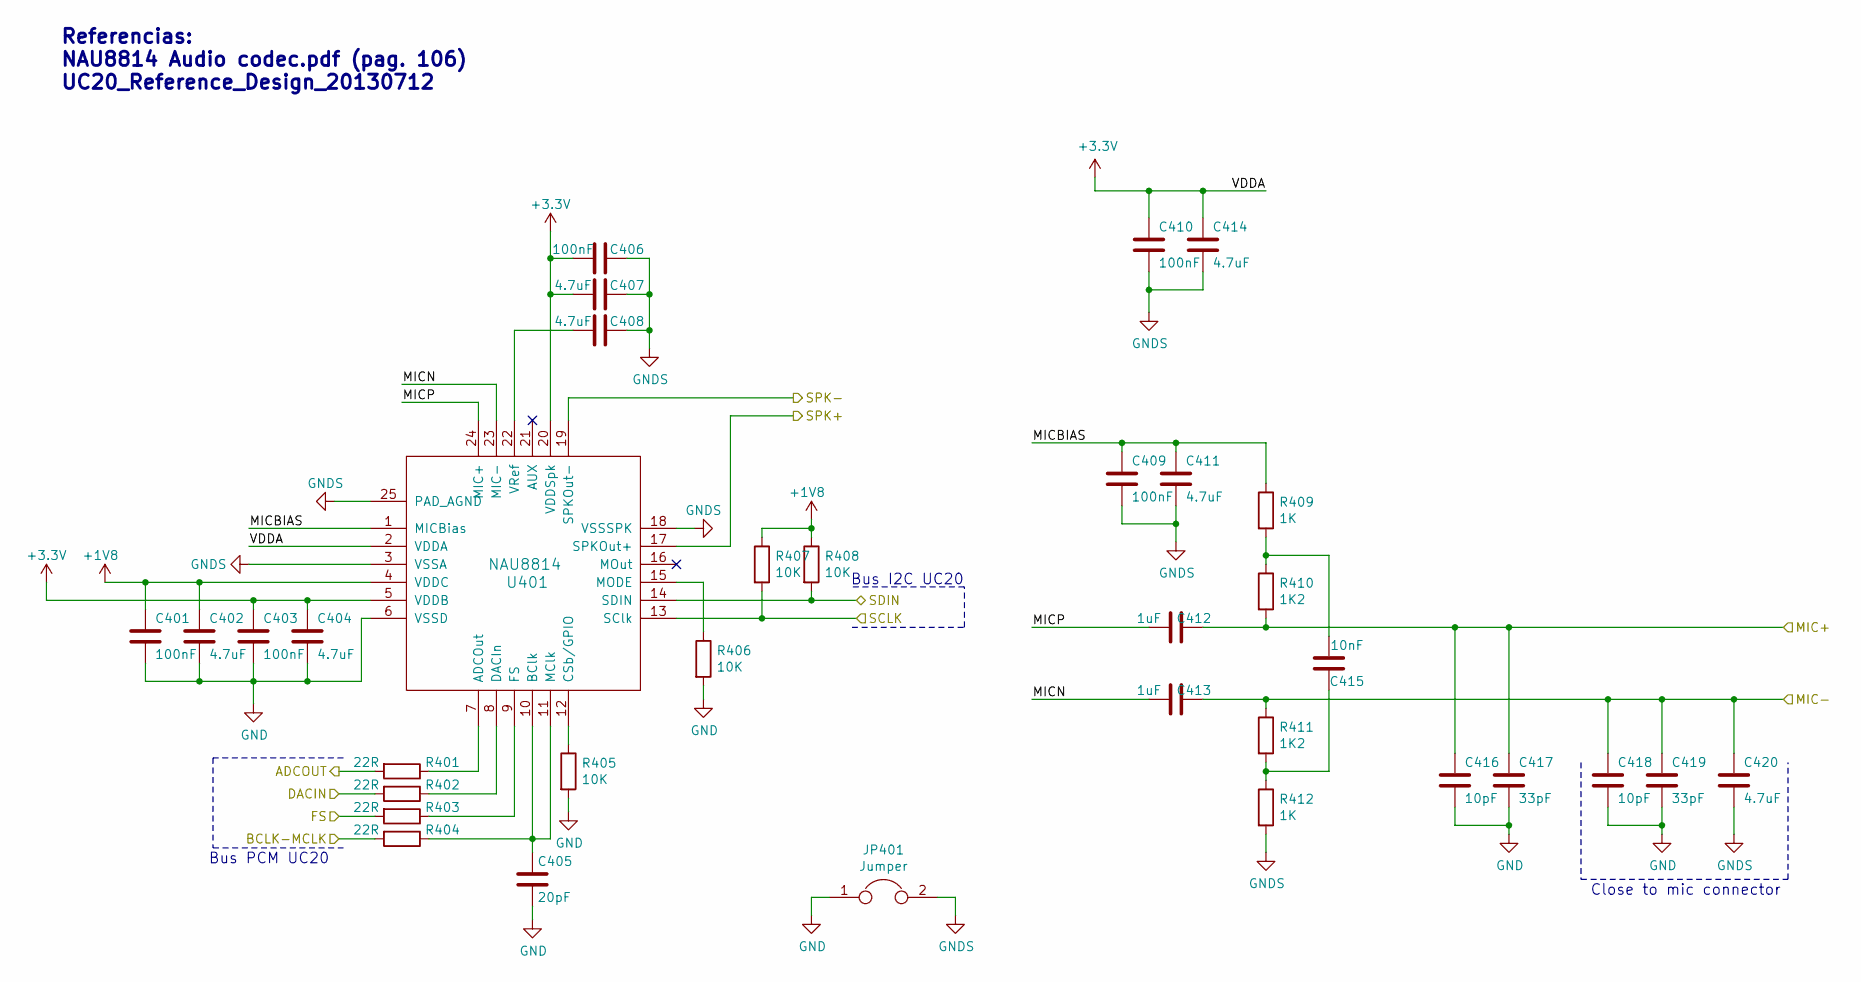
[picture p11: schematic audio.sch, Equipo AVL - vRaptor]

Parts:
C401, C403, C406, C409, C410: 100nF; C_0805_2012Metric_Pad1.15x1.40mm_HandSolder
C402, C404, C407, C408, C411, C414, C420: 4.7uF; C_0805_2012Metric_Pad1.15x1.40mm_HandSolder
C405: 20pF; C_0805_2012Metric_Pad1.15x1.40mm_HandSolder
C412, C413: 1uF; C_0805_2012Metric_Pad1.15x1.40mm_HandSolder
C415: 10nF; C_0805_2012Metric_Pad1.15x1.40mm_HandSolder
C416, C418: 10pF; C_0805_2012Metric_Pad1.15x1.40mm_HandSolder
C417, C419: 33pF; C_0805_2012Metric_Pad1.15x1.40mm_HandSolder
JP401: Jumper; NetTie-2_SMD_Pad0.5mm
R401, R402, R403, R404: 22R; R_0805_2012Metric_Pad1.15x1.40mm_HandSolder
R405, R406, R407, R408: 10K; R_0805_2012Metric_Pad1.15x1.40mm_HandSolder
R409, R412: 1K; R_0805_2012Metric_Pad1.15x1.40mm_HandSolder
R410, R411: 1K2; R_0805_2012Metric_Pad1.15x1.40mm_HandSolder
U401: NAU8814; NAU8814_QFN-24_4x4mm_Pitch0.5mm_EPAD_HandSoldering

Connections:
+1V8: C401.1, C402.1, R407.1, R408.1, U401.4 (VDDC); also elsewhere on the board
+3V3: C403.1, C404.1, C406.1, C407.1, C410.1, C414.1, U401.2 (VDDA), U401.5 (VDDB), U401.20 (VDDSpk); also elsewhere on the board
/Audio/ADCOUT: R401.2; also elsewhere on the board
/Audio/BCLK-MCLK: R404.2; also elsewhere on the board
/Audio/DACIN: R402.2; also elsewhere on the board
/Audio/FS: R403.2; also elsewhere on the board
/Audio/MICBIAS: C409.1, C411.1, R409.1, U401.1 (MICBias)
/Audio/MICN: C413.1, U401.23 (MIC-)
/Audio/MICP: C412.1, U401.24 (MIC+)
/MIC+: C412.2, C416.1, C417.1, R410.2; also elsewhere on the board
/MIC-: C413.2, C418.1, C419.1, C420.1, R411.1; also elsewhere on the board
/SPK+: U401.17 (SPKOut+); also elsewhere on the board
/SPK-: U401.19 (SPKOut-); also elsewhere on the board
/UC20_PCIe/I2C_SCL: R407.2, U401.13 (SClk); also elsewhere on the board
/UC20_PCIe/I2C_SDA: R408.2, U401.14 (SDIN); also elsewhere on the board
GND: C401.2, C402.2, C403.2, C404.2, C405.2, C416.2, C417.2, C418.2, C419.2, JP401.1, R405.2, R406.2, U401.6 (VSSD); also elsewhere on the board
GNDS: C406.2, C407.2, C408.2, C409.2, C410.2, C411.2, C414.2, C420.2, JP401.2, R412.2, U401.3 (VSSA), U401.18 (VSSSPK), U401.25 (PAD_AGND)
unnamed: C405.1, R404.1, U401.10 (BClk), U401.11 (MClk)
unnamed: C408.1, U401.22 (VRef)
unnamed: C415.1, R409.2, R410.1
unnamed: C415.2, R411.2, R412.1
unnamed: R401.1, U401.7 (ADCOut)
unnamed: R402.1, U401.8 (DACIn)
unnamed: R403.1, U401.9 (FS)
unnamed: R405.1, U401.12 (CSb/GPIO)
unnamed: R406.1, U401.15 (MODE)

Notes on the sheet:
Referencias: NAU8814 Audio codec.pdf (pag. 106) UC20_Reference_Design_20130712
Close to mic connector
Bus I2C UC20
Bus PCM UC20

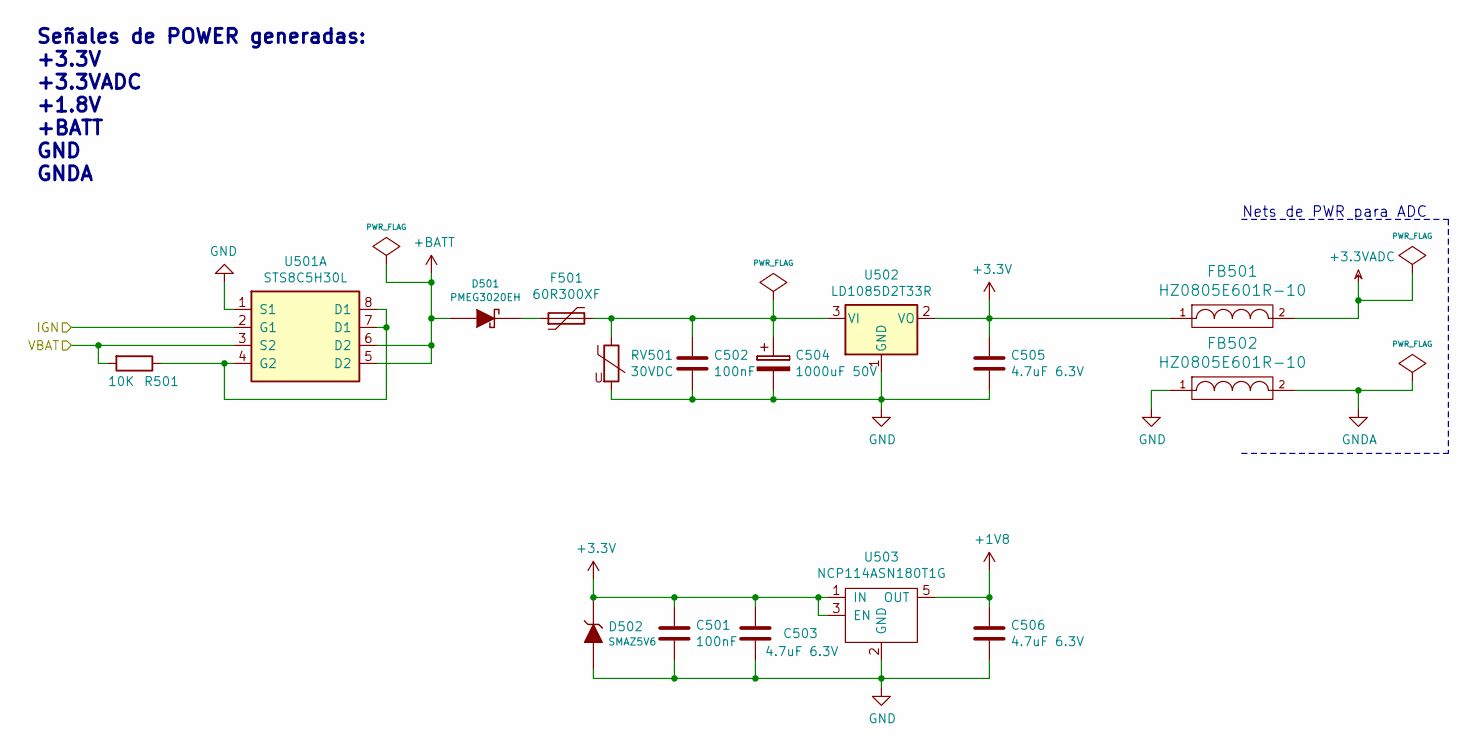
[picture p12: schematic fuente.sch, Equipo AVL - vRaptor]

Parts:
C501, C502: 100nF; C_0805_2012Metric_Pad1.15x1.40mm_HandSolder
C503, C505, C506: 4.7uF 6.3V; C_0805_2012Metric_Pad1.15x1.40mm_HandSolder
C504: 1000uF 50V; CP_Radial_D12.5mm_P5.00mm
D501: PMEG3020EH; D_SOD-123F
D502: SMAZ5V6; DO-214AC (SMA)
F501: 60R300XF
FB501, FB502: HZ0805E601R-10; L_0805_2012Metric_Pad1.15x1.40mm_HandSolder
R501: 10K; R_0805_2012Metric_Pad1.15x1.40mm_HandSolder
RV501: 30VDC; D_1206_3216Metric_Pad1.42x1.75mm_HandSolder
U501: STS8C5H30L; SOIC-8_3.9x4.9mm_P1.27mm
U502: LD1085D2T33R; TO-263-3_TabPin2
U503: NCP114ASN180T1G; TSOP-5_NCP114

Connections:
+1V8: C506.1, U503.5 (OUT); also elsewhere on the board
+3.3VADC: FB501.2; also elsewhere on the board
+3V3: C501.1, C503.1, C505.1, D502.2 (K), FB501.1, U502.2 (VO), U503.1 (IN), U503.3 (EN); also elsewhere on the board
+BATT: D501.1 (A), U501.5 (D2), U501.6 (D2)
/IGN: U501.2 (G1); also elsewhere on the board
/VBAT: R501.2, U501.3 (S2); also elsewhere on the board
GND: C501.2, C502.2, C503.2, C504.2, C505.2, C506.2, D502.1 (A), FB502.1, RV501.2, U501.1 (S1), U502.1 (GND), U503.2 (GND); also elsewhere on the board
GNDA: FB502.2; also elsewhere on the board
unnamed: C502.1, C504.1, F501.2, RV501.1, U502.3 (VI)
unnamed: D501.2 (K), F501.1
unnamed: R501.1, U501.4 (G2), U501.7 (D1), U501.8 (VSS)

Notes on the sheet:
Nets de PWR para ADC
Señales de POWER generadas: +3.3V +3.3VADC +1.8V +BATT GND GNDA

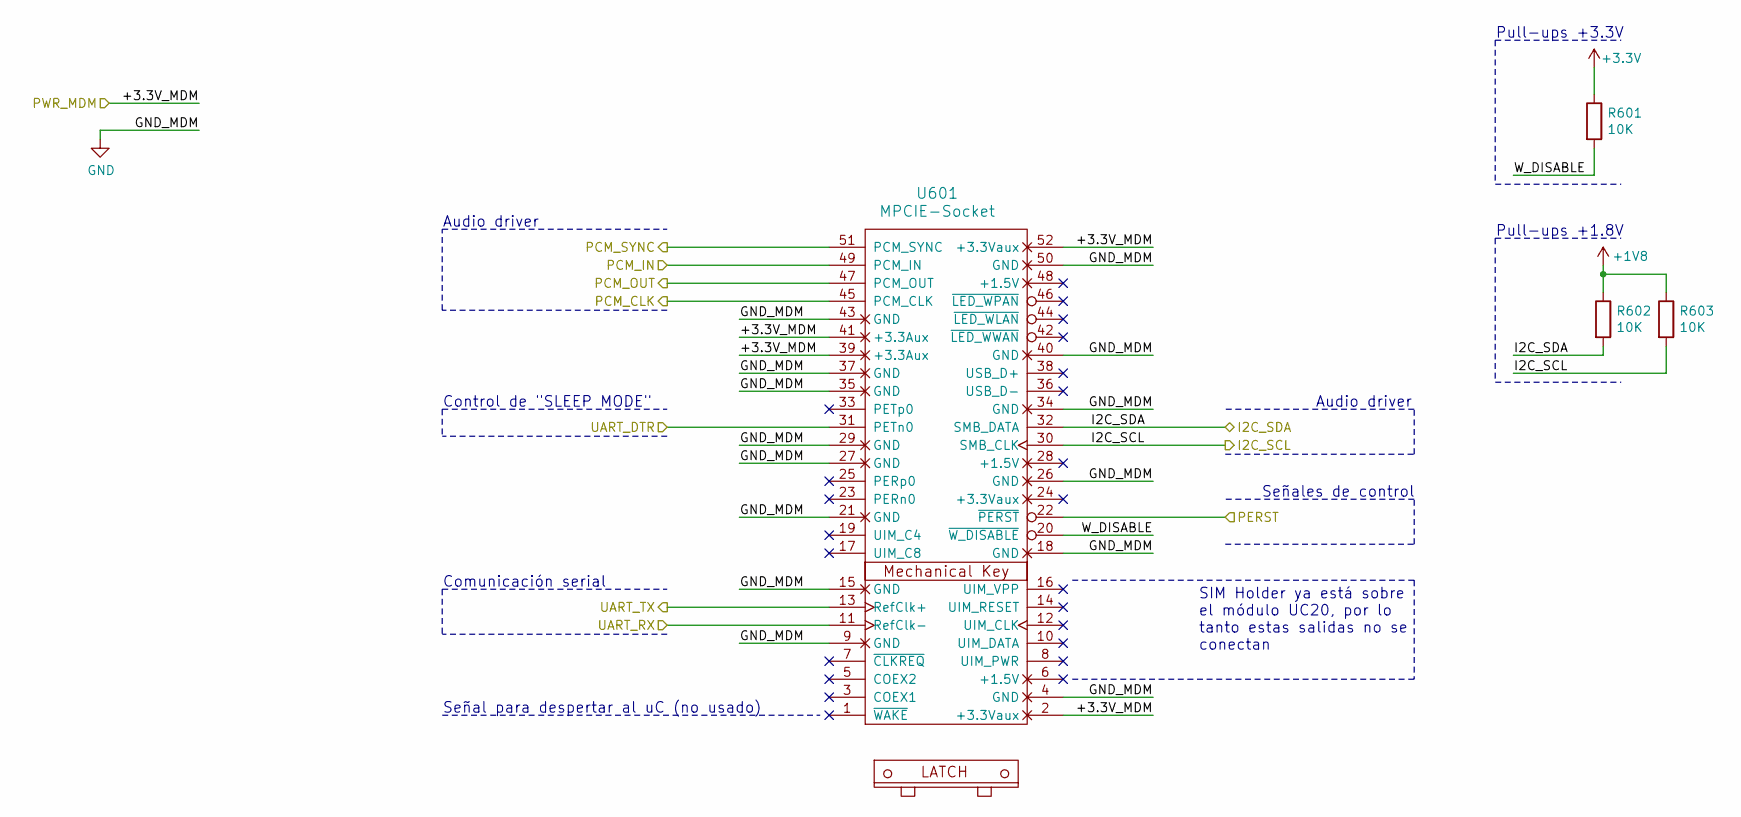
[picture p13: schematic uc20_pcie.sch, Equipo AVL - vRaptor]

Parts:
R601, R602, R603: 10K; R_0805_2012Metric_Pad1.15x1.40mm_HandSolder
U601: MPCIE-Socket; mpcie-socket-latch

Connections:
+1V8: R602.1, R603.1; also elsewhere on the board
+3V3: R601.1; also elsewhere on the board
/Audio/ADCOUT: U601.49 (PCM_IN); also elsewhere on the board
/Audio/BCLK-MCLK: U601.45 (PCM_CLK); also elsewhere on the board
/Audio/DACIN: U601.47 (PCM_OUT); also elsewhere on the board
/Audio/FS: U601.51 (PCM_SYNC); also elsewhere on the board
/CPU/PERST: U601.22 (~PERST); also elsewhere on the board
/CPU/PWR_MDM: U601.2 (+3.3Vaux), U601.39 (+3.3Aux), U601.41 (+3.3Aux), U601.52 (+3.3Vaux); also elsewhere on the board
/CPU/SLEEP_MDM: U601.31 (PETn0); also elsewhere on the board
/CPU/U3_RX: U601.13 (RefClk+); also elsewhere on the board
/CPU/U3_TX: U601.11 (RefClk-); also elsewhere on the board
/UC20_PCIe/I2C_SCL: R603.2, U601.30 (SMB_CLK); also elsewhere on the board
/UC20_PCIe/I2C_SDA: R602.2, U601.32 (SMB_DATA); also elsewhere on the board
/UC20_PCIe/W_DISABLE: R601.2, U601.20 (~W_DISABLE)
GND: U601.4 (GND), U601.9 (GND), U601.15 (GND), U601.18 (GND), U601.21 (GND), U601.26 (GND), U601.27 (GND), U601.29 (GND), U601.34 (GND), U601.35 (GND), U601.37 (GND), U601.40 (GND), U601.43 (GND), U601.50 (GND); also elsewhere on the board

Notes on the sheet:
Control de "SLEEP MODE"
Audio driver
Comunicación serial
Pull-ups +3.3V
Pull-ups +1.8V
Señales de control
SIM Holder ya está sobre el módulo UC20, por lo tanto estas salidas no se conectan
Señal para despertar al uC (no usado)

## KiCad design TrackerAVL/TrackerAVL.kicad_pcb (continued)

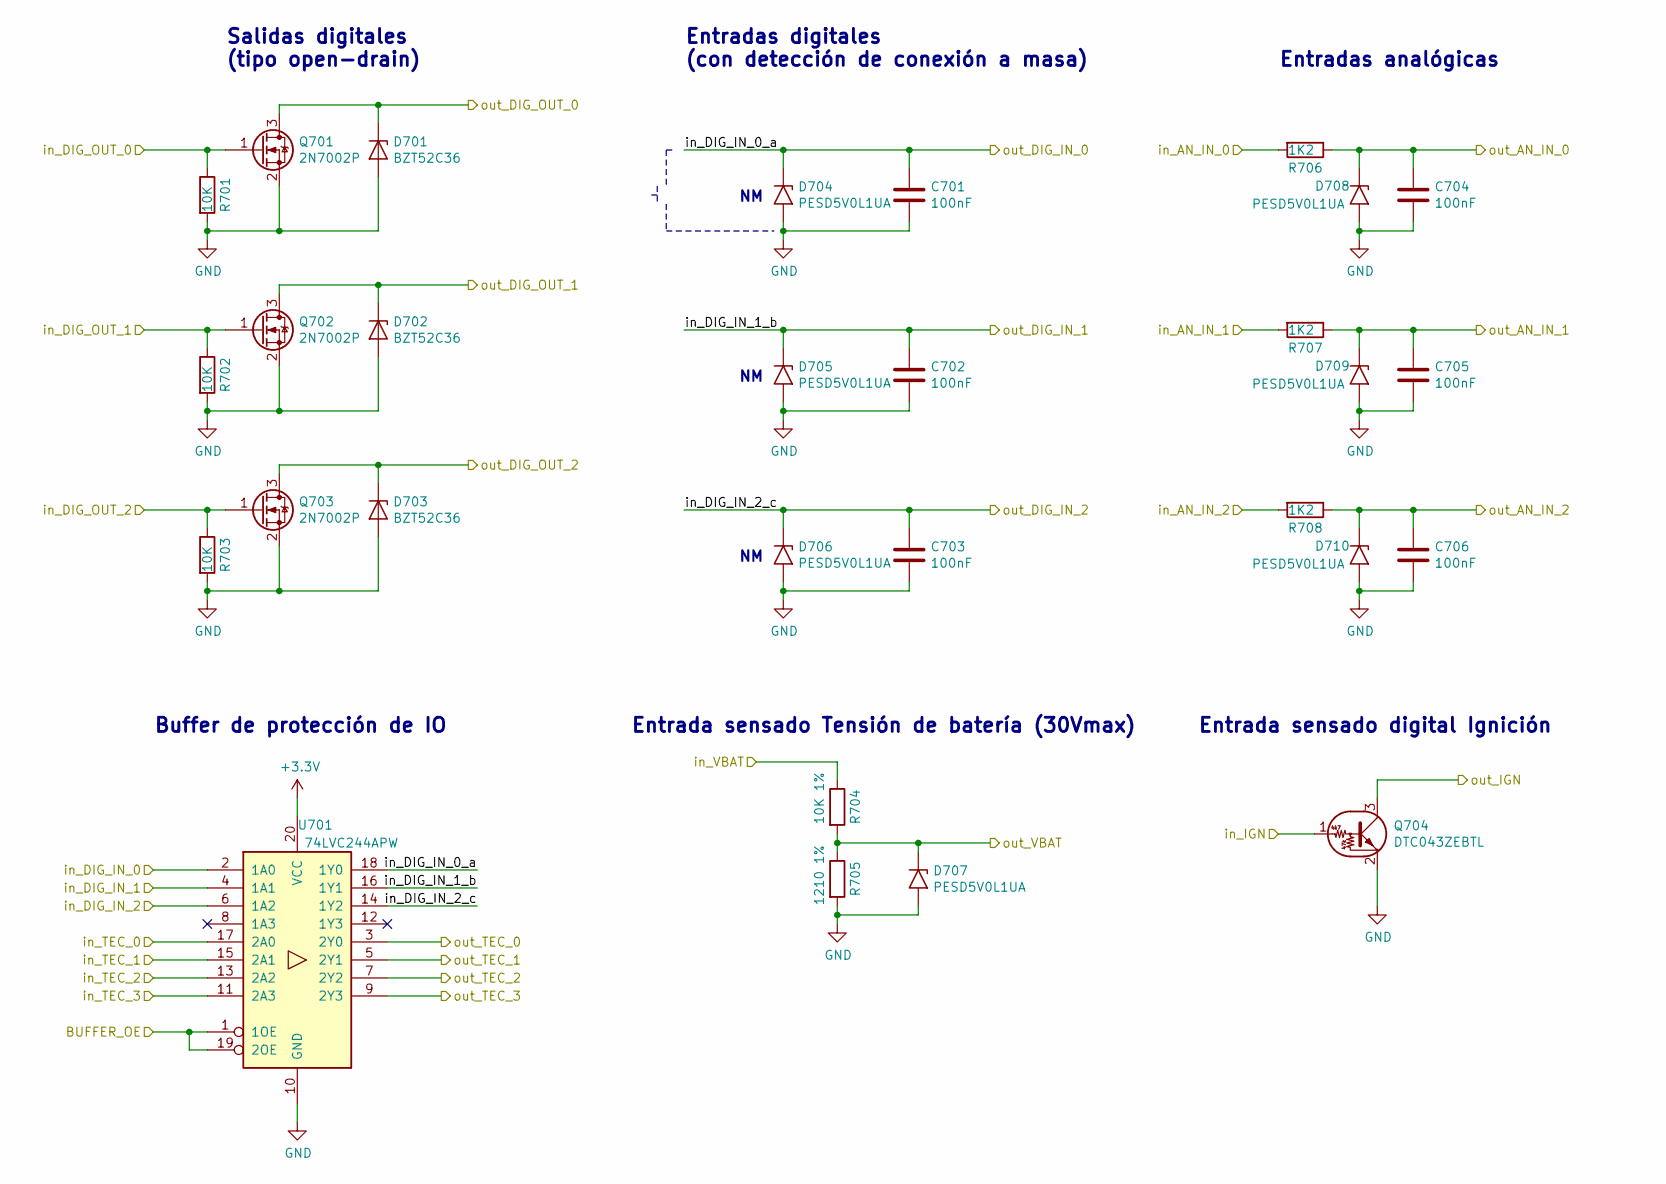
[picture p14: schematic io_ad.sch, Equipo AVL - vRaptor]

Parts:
C701, C702, C703, C704, C705, C706: 100nF; C_0805_2012Metric_Pad1.15x1.40mm_HandSolder
D701, D702, D703: BZT52C36; D_SOD-123
D704, D705, D706, D707, D708, D709, D710: PESD5V0L1UA; D_SOD-323_HandSoldering
Q701, Q702, Q703: 2N7002P; SOT-23_Handsoldering
Q704: DTC043ZEBTL; SOT-523_(SOT-416)
R701, R702, R703: 10K; R_0805_2012Metric_Pad1.15x1.40mm_HandSolder
R704: 10K 1%; R_0805_2012Metric_Pad1.15x1.40mm_HandSolder
R705: 1210 1%; R_0805_2012Metric_Pad1.15x1.40mm_HandSolder
R706, R707, R708: 1K2; R_0805_2012Metric_Pad1.15x1.40mm_HandSolder
U701: 74LVC244APW; TSSOP-20_4.4x6.5mm_P0.65mm

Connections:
+3V3: U701.20 (VCC); also elsewhere on the board
/AN_IN_0: R706.2; also elsewhere on the board
/AN_IN_1: R707.2; also elsewhere on the board
/AN_IN_2: R708.2; also elsewhere on the board
/CPU/AN_IN_0: C704.1, D708.1 (A1), R706.1; also elsewhere on the board
/CPU/AN_IN_1: C705.1, D709.1 (A1), R707.1; also elsewhere on the board
/CPU/AN_IN_2: C706.1, D710.1 (A1), R708.1; also elsewhere on the board
/CPU/BUFFER_OE: U701.1 (1OE), U701.19 (2OE); also elsewhere on the board
/CPU/DIG_IN_0: C701.1, D704.1 (A1), U701.18 (1Y0); also elsewhere on the board
/CPU/DIG_IN_1: C702.1, D705.1 (A1), U701.16 (1Y1); also elsewhere on the board
/CPU/DIG_IN_2: C703.1, D706.1 (A1), U701.14 (1Y2); also elsewhere on the board
/CPU/DIG_OUT_0: Q701.1 (G), R701.1; also elsewhere on the board
/CPU/DIG_OUT_1: Q702.1 (G), R702.1; also elsewhere on the board
/CPU/DIG_OUT_2: Q703.1 (G), R703.1; also elsewhere on the board
/CPU/IGN: Q704.3 (C); also elsewhere on the board
/CPU/TEC_0: U701.3 (2Y0); also elsewhere on the board
/CPU/TEC_1: U701.5 (2Y1); also elsewhere on the board
/CPU/TEC_2: U701.7 (2Y2); also elsewhere on the board
/CPU/TEC_3: U701.9 (2Y3); also elsewhere on the board
/CPU/VBAT: D707.1 (A1), R704.2, R705.1; also elsewhere on the board
/DIG_IN_0: U701.2 (1A0); also elsewhere on the board
/DIG_IN_1: U701.4 (1A1); also elsewhere on the board
/DIG_IN_2: U701.6 (1A2); also elsewhere on the board
/DIG_OUT_0: D701.1 (K), Q701.3 (D); also elsewhere on the board
/DIG_OUT_1: D702.1 (K), Q702.3 (D); also elsewhere on the board
/DIG_OUT_2: D703.1 (K), Q703.3 (D); also elsewhere on the board
/IGN: Q704.1 (B); also elsewhere on the board
/TEC_0: U701.17 (2A0); also elsewhere on the board
/TEC_1: U701.15 (2A1); also elsewhere on the board
/TEC_2: U701.13 (2A2); also elsewhere on the board
/TEC_3: U701.11 (2A3); also elsewhere on the board
/VBAT: R704.1; also elsewhere on the board
GND: C701.2, C702.2, C703.2, C704.2, C705.2, C706.2, D701.2 (A), D702.2 (A), D703.2 (A), D704.2 (A2), D705.2 (A2), D706.2 (A2), D707.2 (A2), D708.2 (A2), D709.2 (A2), D710.2 (A2), Q701.2 (S), Q702.2 (S), Q703.2 (S), Q704.2 (E), R701.2, R702.2, R703.2, R705.2, U701.10 (GND); also elsewhere on the board

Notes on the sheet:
Salidas digitales (tipo open-drain)
Entradas digitales (con detección de conexión a masa)
Entradas analógicas
Entrada sensado Tensión de batería (30Vmax)
Entrada sensado digital Ignición
Buffer de protección de IO

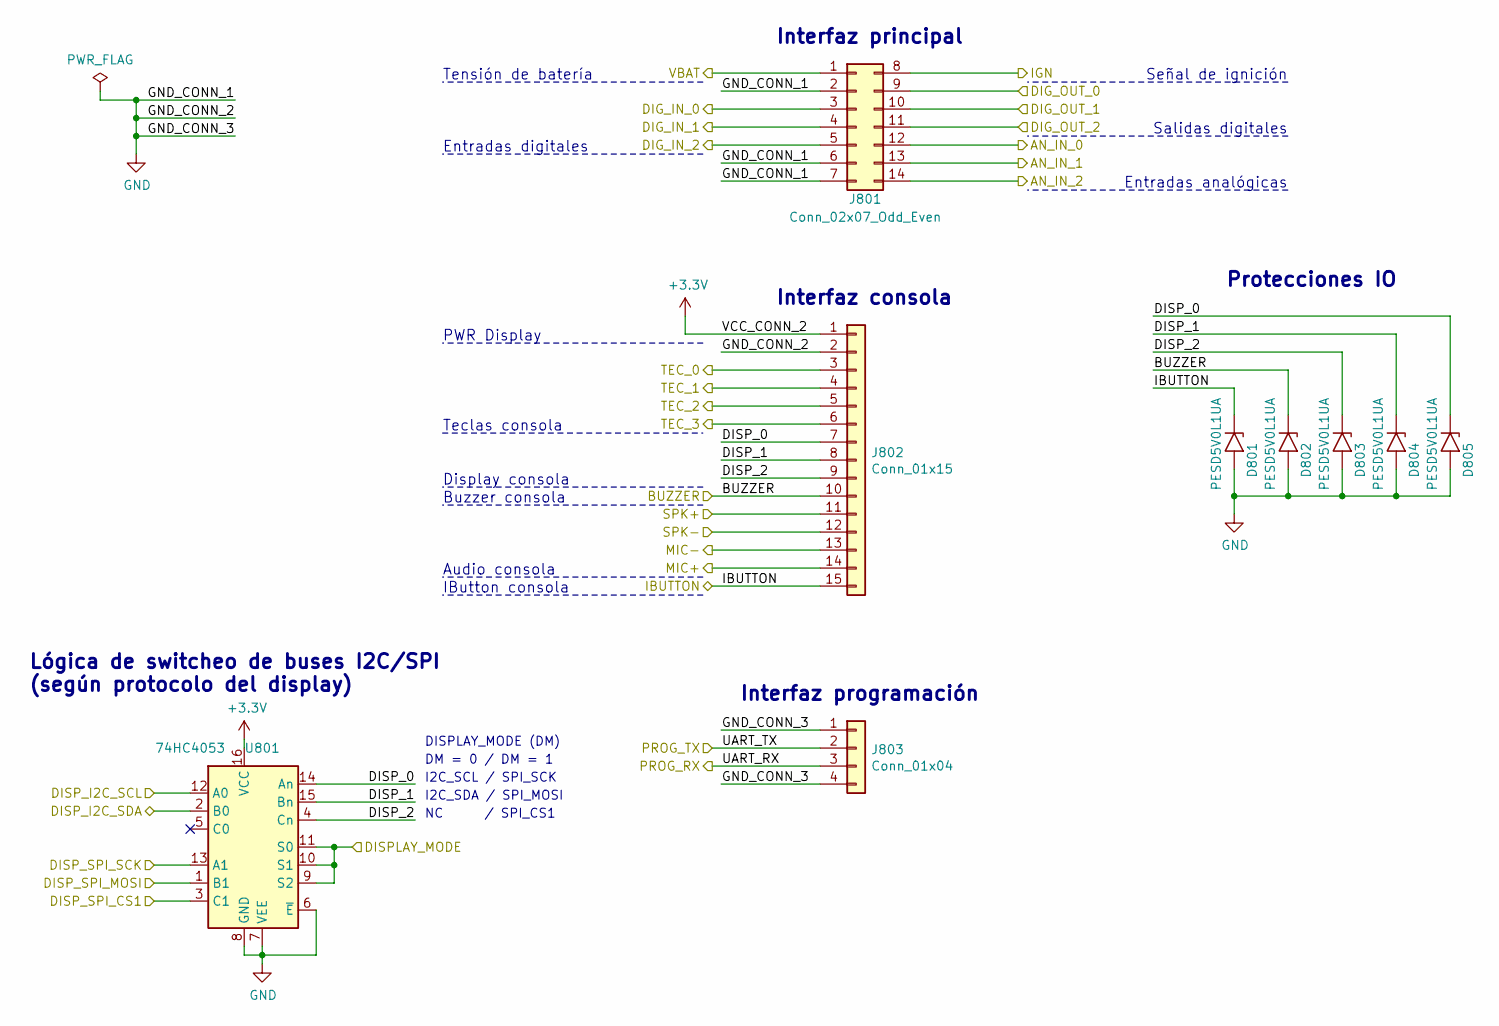
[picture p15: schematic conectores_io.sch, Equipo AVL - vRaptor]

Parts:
D801, D802, D803, D804, D805: PESD5V0L1UA; D_SOD-323_HandSoldering
J801: Conn_02x07_Odd_Even; Molex_Micro-Fit_3.0_43045-1406_2x07-1MP_P3.00mm_Horizontal
J802: Conn_01x15; Molex_Pico_SPOX_87438-0443_1x15
J803: Conn_01x04; Molex_Pico_SPOX_87438-0443_1x04
U801: 74HC4053; SOIC-16_3.9x9.9mm_P1.27mm

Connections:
+3V3: J802.1, U801.16 (VCC); also elsewhere on the board
/AN_IN_0: J801.12; also elsewhere on the board
/AN_IN_1: J801.13; also elsewhere on the board
/AN_IN_2: J801.14; also elsewhere on the board
/CPU/BUZZER: D802.1 (A1), J802.10; also elsewhere on the board
/CPU/DISPLAY_MODE: U801.9 (S2), U801.10 (S1), U801.11 (S0); also elsewhere on the board
/CPU/IBUTTON: D801.1 (A1), J802.15; also elsewhere on the board
/Conectores_IO/DISP_0: D805.1 (A1), J802.7, U801.14 (An)
/Conectores_IO/DISP_1: D804.1 (A1), J802.8, U801.15 (Bn)
/Conectores_IO/DISP_2: D803.1 (A1), J802.9, U801.4 (Cn)
/Conectores_IO/DISP_SPI_CS1: U801.3 (C1); also elsewhere on the board
/Conectores_IO/PROG_RX: J803.3; also elsewhere on the board
/Conectores_IO/PROG_TX: J803.2; also elsewhere on the board
/DIG_IN_0: J801.3; also elsewhere on the board
/DIG_IN_1: J801.4; also elsewhere on the board
/DIG_IN_2: J801.5; also elsewhere on the board
/DIG_OUT_0: J801.9; also elsewhere on the board
/DIG_OUT_1: J801.10; also elsewhere on the board
/DIG_OUT_2: J801.11; also elsewhere on the board
/I2C_SCL: U801.12 (A0); also elsewhere on the board
/I2C_SDA: U801.2 (B0); also elsewhere on the board
/IGN: J801.8; also elsewhere on the board
/MIC+: J802.14; also elsewhere on the board
/MIC-: J802.13; also elsewhere on the board
/SPI_MOSI: U801.1 (B1); also elsewhere on the board
/SPI_SCK: U801.13 (A1); also elsewhere on the board
/SPK+: J802.11; also elsewhere on the board
/SPK-: J802.12; also elsewhere on the board
/TEC_0: J802.3; also elsewhere on the board
/TEC_1: J802.4; also elsewhere on the board
/TEC_2: J802.5; also elsewhere on the board
/TEC_3: J802.6; also elsewhere on the board
/VBAT: J801.1; also elsewhere on the board
GND: D801.2 (A2), D802.2 (A2), D803.2 (A2), D804.2 (A2), D805.2 (A2), J801.2, J801.6, J801.7, J802.2, J803.1, J803.4, U801.6 (~E), U801.7 (VEE), U801.8 (GND); also elsewhere on the board

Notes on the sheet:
PWR Display
Teclas consola
Display consola
Audio consola
IButton consola
Entradas digitales
Tensión de batería
Señal de ignición
Salidas digitales
Entradas analógicas
Interfaz principal
Interfaz consola
Interfaz programación
Protecciones IO
Buzzer consola
Lógica de switcheo de buses I2C/SPI (según protocolo del display)
I2C_SCL / SPI_SCK
I2C_SDA / SPI_MOSI
NC / SPI_CS1
DM = 0 / DM = 1
DISPLAY_MODE (DM)

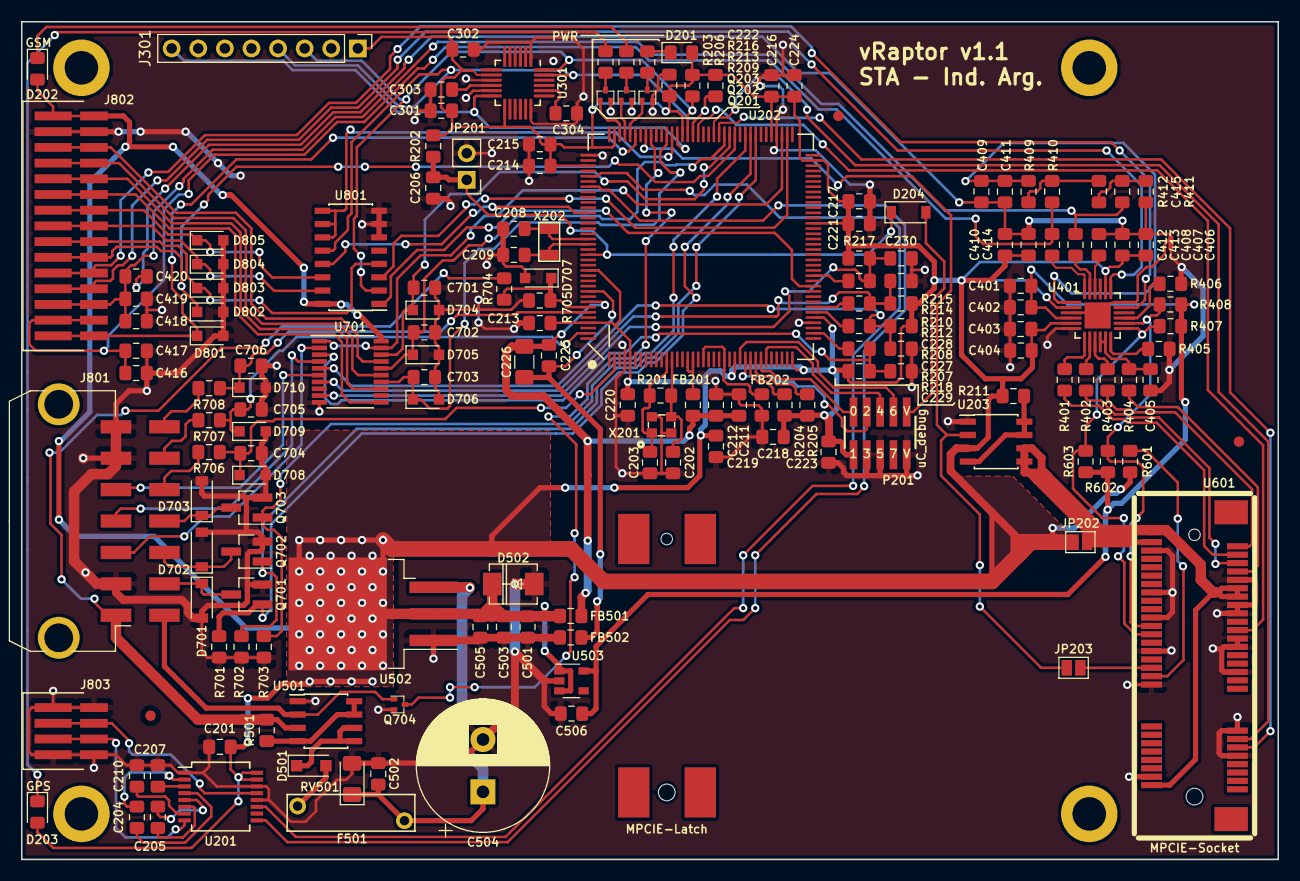
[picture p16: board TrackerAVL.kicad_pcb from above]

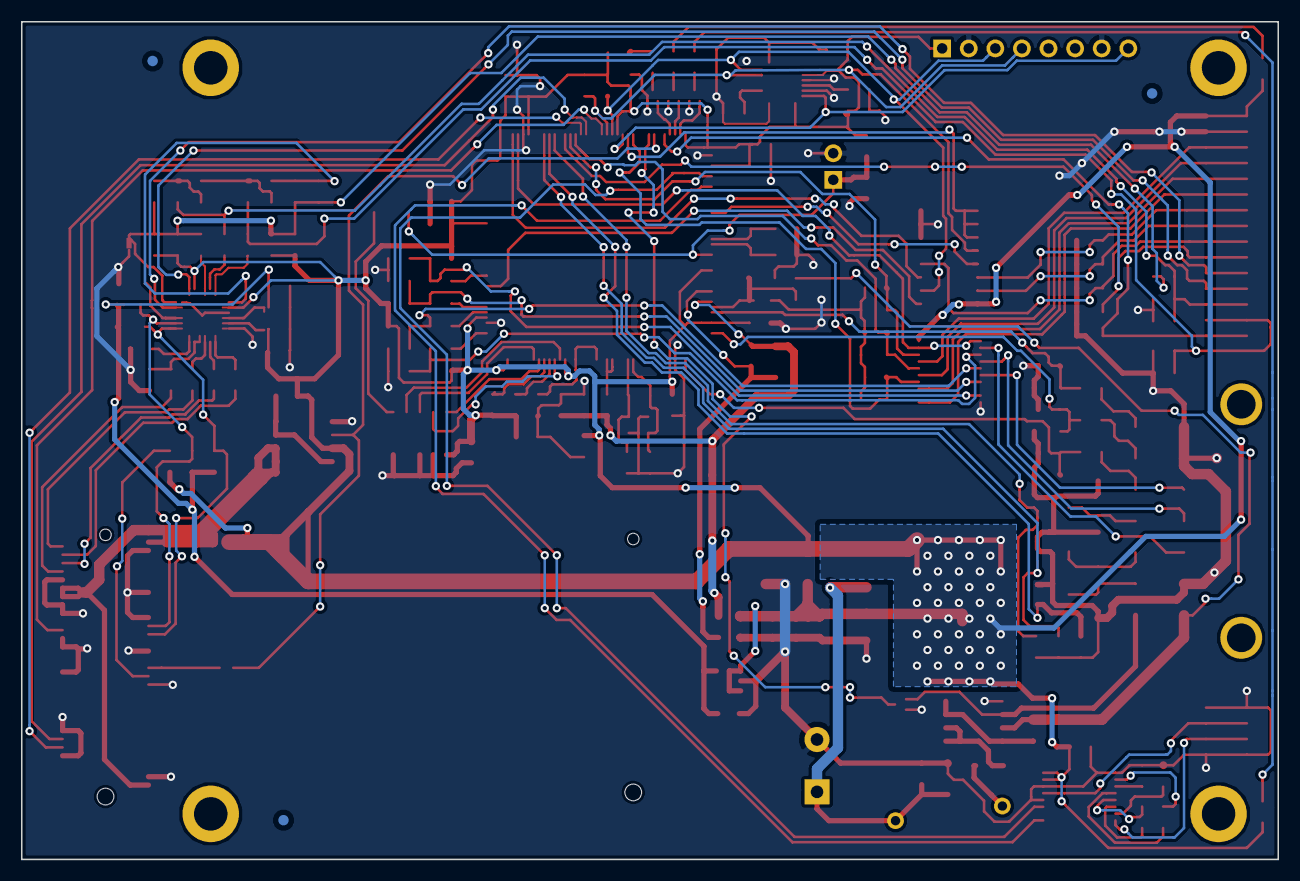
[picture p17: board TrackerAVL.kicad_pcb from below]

Board: 2 copper layers, 120.0 x 80.0 mm, 174 parts (3 on the bottom side), 122 nets.

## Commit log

2018-09-25 Agrego archivos. Trabajando en esquemático.
    [ON_BOARD_IO.sch, TrackerAVL.kicad_pcb, TrackerAVL.sch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]
2018-09-25 Cambios en sch
    [TrackerAVL.sch, audio.sch, fuente.sch]
2018-10-13 Cambios en sch y adición de documentación
    [ON_BOARD_IO.sch, TrackerAVL.sch, acelerometro.sch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]
2018-10-18 Cambios en sch y add docs
    [audio.sch]
2018-10-30 EquipoAVL-vRaptor1.0 sch-finalizado
    [cpu.sch, io_ad.sch]
2018-10-30 Cambios en pcb
    [TrackerAVL.kicad_pcb, cpu.sch]
2018-11-02 Esquemático: se corrige símbolo FILTROS
    [fuente.sch]
2018-11-05 Cambios en pcb y modelos 3d
    [TrackerAVL.kicad_pcb, _saved_fuente.sch]
2018-11-07 PCB terminado, pendiente revisión
    [TrackerAVL.kicad_pcb]
2018-11-08 Se modifica huella NAU8814 a QFN-24_HandSoldering
    Falta modificar resto de huellas
    [TrackerAVL.kicad_pcb, audio.sch]
2018-11-08 Se modifica huella NAU8814 a QFN-24_HandSoldering
    [TrackerAVL.kicad_pcb, TrackerAVL.sch, acelerometro.sch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]
2018-11-10 Se modifica huella MPU6050 a QFN-24_HandSoldering
    Pendiente hacer cambios de pistas según recomendaciones que figuran en el diseño del pcb.
    [TrackerAVL.kicad_pcb, TrackerAVL.sch, acelerometro.sch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]
2018-11-13 Últimos cambios en pcb
    [TrackerAVL.kicad_pcb]
2018-11-13 Modificaciones varias
    Se modifica acceso de pistas a pads (ahora a 90°).
    Se agregan archivos de información al proyecto.
    Se corrigen elementos 3d 24-QFN.
    Modificaciones varias de pistas.
    [TrackerAVL.kicad_pcb]
2018-11-14 Cambio de nombre de archivo
2018-11-14 modificaciones en pcb
    [TrackerAVL.kicad_pcb]
2018-11-14 PCB terminado, para su revisión final
    [TrackerAVL.kicad_pcb]
2018-11-15 Cambios en README, ahora incluye información de versiones
    [TrackerAVL.kicad_pcb, TrackerAVL.sch, acelerometro.sch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]
2018-11-15 Generación de archivos gerber, drills, bom
    [TrackerAVL-B.Cu.gbr, TrackerAVL-B.Mask.gbr, TrackerAVL-B.Paste.gbr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]
2018-11-15 Preparación de gerbers para enviar a fabricante Elecrow
    [TrackerAVL-B.Cu.gbl, TrackerAVL-B.Mask.gbs, TrackerAVL-B.Paste.gbp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]
2018-11-30 Update BOM files and README
    [Equipo AVL vRaptor v1.0 BOM.ods, Equipo AVL vRaptor v1.1 BOM_Componentes efectivos.xlsx, Equipo AVL vRaptor v1.1 BOM_Original.xlsx]
